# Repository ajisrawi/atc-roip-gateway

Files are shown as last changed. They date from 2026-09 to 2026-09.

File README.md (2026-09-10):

# ATC RoIP Gateway (VHF + HF, airborne)

Radio-over-IP gateway for aircraft ATC radios: bridges a VHF COM and an HF
transceiver to an IP network (Starlink aviation terminal) with an ED-137-style
RTP audio + PTT/COR stream.

```
Pilot/remote op ⇄ RTP over IP (Starlink) ⇄ [this gateway] ⇄ VHF COM + HF transceivers
```

## Deliverables

| Item | Where | Status |
|---|---|---|
| **Design document (PDF)** | `ATC-RoIP-Gateway-Design-Document.pdf` | 16 pages: study, diagrams, PCB, BOM, verification + schematic appendix |
| **Market study** | `docs/01-market-study.md` | sourced |
| **Design spec** | `docs/02-design-spec.md` | rev A |
| **Schematics** | `hardware/atc-roip-gateway/*.kicad_sch` | ERC 0 errors / 0 warnings, wired stubs + net labels |
| **PCB (4-layer, 125×95 mm)** | `hardware/atc-roip-gateway/atc-roip-gateway.kicad_pcb` | fully routed, 0 unconnected, 0 electrical DRC |
| **Fab outputs** | `hardware/atc-roip-gateway/fab/` | Gerber ZIP, drill, pick-and-place |
| **BOM** | `docs/BOM.csv` | 40 line items, 100 parts, MPNs assigned |
| **Firmware** | `firmware/` | ED-137-style stack (SIP + RTP/PTT/SQU + G.711), CMake, flash script |
| **Generators** | `tools/` | schematic/PCB/BOM/doc generation + checks (reproducible) |

## Hardware summary
| Block | Part |
|---|---|
| MCU | STM32H743VIT6 (Ethernet MAC + SAI, runs lwIP + RTP) |
| Ethernet | LAN8742A RMII PHY + magnetics-integrated RJ45 |
| Audio | TLV320AIC23B stereo codec — Left = VHF, Right = HF |
| Radio isolation | 600:600 Ω transformers (RX/TX ×2), PC817 optos (PTT + COR ×2) |
| Radio connector | DB25 (pinout in design spec §5.1) |
| Power | 28 V DC bus → LM2576HV-5.0 buck → AMS1117-3.3, split analog rail |

## Regenerating everything
```bash
python tools/design.py            # schematics
python tools/make_bom.py          # BOM from netlist
python tools/make_design_doc.py   # design document PDF
# PCB: tools/make_pcb.py (placement) + Freerouting + tools/power_fanout_final.py
```

## Status / caveats
- Rev A prototype: not TSO'd, no DO-160 qualification, no DO-178C artifacts.
- ED-137: hardware + firmware structured for the ED-137B Radio profile; exact
  extension bit-fields and SDP attributes must be verified against the
  licensed EUROCAE text + a conformance tool before claiming compliance.
- Transformer footprint (DIP-4) and DB25 gender are placeholders — confirm
  against the chosen audio transformer and aircraft harness.
- Firmware builds against STM32CubeH7 (user fetches; see `firmware/README.md`)
  and needs the four board-config files copied per `firmware/src/config/README.md`.

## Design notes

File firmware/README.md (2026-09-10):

# ATC RoIP Gateway — Firmware

ED-137-style Radio-over-IP firmware for the STM32H743 gateway board:
SIP session endpoint + RTP audio (G.711 µ-law @ 8 kHz) with the ED-137
Radio-profile RTP header extension carrying PTT and squelch (SQU), R2S-style
keepalives, TLV320AIC23B codec driver, and isolated PTT/COR radio signaling.
Two channels: **VHF = left**, **HF = right** audio channel.

```
firmware/
├── CMakeLists.txt            build (arm-none-eabi-gcc, CMake)
├── cmake/arm-none-eabi.cmake toolchain file
├── flash.ps1                 flash helper (STM32CubeProgrammer CLI)
├── src/
│   ├── main.c                init + superloop
│   ├── board.h               pin map (matches schematic rev A)
│   ├── app_config.h          network / codec / behaviour settings
│   ├── ed137/
│   │   ├── rtp_ed137.h/.c    RTP + ED-137 header ext (PTT type, SQU), R2S
│   │   ├── sip_mini.h/.c     minimal SIP UA (INVITE/ACK/BYE/OPTIONS + SDP)
│   │   └── g711.h/.c         µ-law encode/decode
│   ├── audio/
│   │   ├── aic23.h/.c        TLV320AIC23B register driver (I2C)
│   │   └── sai_stream.h/.c   SAI1 DMA double-buffer streaming
│   ├── net/
│   │   └── roip_chan.h/.c    per-radio channel: jitter buffer, PTT/COR logic
│   └── dsp/
│       └── voxagc.h/.c       HPF + AGC + VOX squelch (HF conditioning)
└── third_party/              (you fetch: STM32CubeH7 → HAL + lwIP + CMSIS)
```

## Dependencies (fetch once)

The application code is self-contained; it builds against ST's HAL, CMSIS and
lwIP from the official STM32CubeH7 package:

```bash
git clone --depth 1 https://github.com/STMicroelectronics/STM32CubeH7 third_party/STM32CubeH7
```

Toolchain: [Arm GNU Toolchain](https://developer.arm.com/downloads/-/arm-gnu-toolchain-downloads)
(`arm-none-eabi-gcc`) and CMake ≥ 3.20 — or open the tree in **STM32CubeIDE**
and add `src/` to a generated STM32H743VITx project (easiest route).

## Build

```bash
cmake -B build -DCMAKE_TOOLCHAIN_FILE=cmake/arm-none-eabi.cmake
cmake --build build
```

Produces `build/atc-roip-gw.elf` / `.bin` / `.hex`.

## Flash (two ways)

**1. SWD via ST-LINK on header J2** (3V3, SWDIO, SWCLK, GND, NRST):

```powershell
./flash.ps1            # uses STM32_Programmer_CLI, SWD
```

**2. USB-less DFU fallback: system bootloader over UART on J3**
(BOOT0 high at reset → STM32 bootloader; then):

```powershell
STM32_Programmer_CLI -c port=COMx br=115200 -w build/atc-roip-gw.bin 0x08000000 -v -rst
```

Install [STM32CubeProgrammer](https://www.st.com/en/development-tools/stm32cubeprog.html)
for `STM32_Programmer_CLI`.

## Configuration

Edit `src/app_config.h` (static IP / DHCP, peer address, SIP on/off, codec
G.711 vs pass-through, VOX thresholds), or use the UART console on J3
(115200 8N1) at runtime — type `help`.

## ED-137 compliance status

Implemented toward the **ED-137B Radio profile**: SIP INVITE/ACK/BYE/OPTIONS
with WG67-style SDP (`a=type:radio`), RTP/PCMU 8 kHz, RTP header extension
carrying PTT type + SQU + PTT-id, and periodic R2S-style keepalive while idle.
The exact bit numbering of the extension word and the WG67 SDP attribute set
MUST be verified against the licensed EUROCAE ED-137B/C text and a conformance
tool (e.g. GL MAPS ED-137) before claiming compliance — constants live in one
place (`rtp_ed137.h`) to make that adjustment trivial.

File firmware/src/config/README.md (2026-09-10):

# Board config files (copy-and-adapt from STM32CubeH7)

This directory holds the four project-config files that STM32CubeH7 provides
as templates. Copy them from the Cube tree after cloning it and adjust:

| File | Copy from | Adjust |
|---|---|---|
| `stm32h7xx_hal_conf.h` | `Drivers/STM32H7xx_HAL_Driver/Inc/stm32h7xx_hal_conf_template.h` | enable HAL_ETH/SAI/I2C/UART/DMA modules, HSE_VALUE 25 MHz |
| `lwipopts.h` | any H7 lwIP example (`Projects/NUCLEO-H743ZI/Applications/LwIP/...`) | `NO_SYS 1`, `LWIP_DHCP 1`, UDP enabled, no TCP needed |
| `ethernetif.c/.h` | same lwIP example | RMII pins per `src/board.h` (PA1/PA2/PA7, PC1/PC4/PC5, PB11/PB12/PB13), PHY address 0 (LAN8742) |
| `STM32H743VITx_FLASH.ld` | `Projects/.../STM32H743ZITX_FLASH.ld` | add a `.dma_buf` section in D2 SRAM (0x30000000) for the SAI/ETH DMA buffers |

The NUCLEO-H743ZI lwIP example is the closest starting point — same MCU
family, same LAN8742 PHY, same RMII wiring except the TX_EN/TXD0/TXD1 port
choices, which `src/board.h` documents.

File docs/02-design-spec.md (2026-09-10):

# ATC RoIP Gateway — Design Specification

Airborne Radio-over-IP gateway that bridges **two aircraft transceivers (VHF COM +
HF)** to an **IP network (Starlink aviation terminal / aircraft LAN)** using an
ED-137-style RTP audio + PTT/COR signaling stream.

```
                             ┌─────────────────────────────────────────────┐
 VHF COM ──audio/PTT/COR──►  │  [radio_if]      [audio]      [mcu]   [eth] │
 HF XCVR ──audio/PTT/COR──►  │  transformers → TLV320AIC23 → STM32H7 → PHY ├──RJ45──► Starlink router
                             │  + PC817 optos    stereo codec  RTP/Opus    │           │
 28V DC bus ───────────────► │  [power] 28V → 5V buck → 3.3V / 3.3VA       │           ▼
                             └─────────────────────────────────────────────┘   ATC IP network / remote op
```

## KiCad project
`hardware/atc-roip-gateway/` — KiCad 8+ format (opens in KiCad 8/9/10).

| Sheet | File | Content |
|---|---|---|
| Root | `atc-roip-gateway.kicad_sch` | block notes + sheet index |
| Power | `power.kicad_sch` | 28 V bus input, protection, 5 V buck, 3.3 V LDO, analog rail split |
| MCU | `mcu.kicad_sch` | STM32H743VIT6, crystal, SWD, UART, PTT/COR GPIO, status LEDs |
| Ethernet | `ethernet.kicad_sch` | LAN8742A RMII PHY, 25 MHz crystal, magnetics-integrated RJ45 |
| Audio | `audio.kicad_sch` | TLV320AIC23B stereo codec (L = VHF, R = HF), coupling networks |
| Radio IF | `radio_if.kicad_sch` | 600 Ω isolation transformers ×4, PC817 optos ×4, DB25 |

Validation: `kicad-cli sch erc` — **0 errors, 0 warnings**; netlist connectivity
machine-checked (`tools/check_netlist.py`, 14 signal-path assertions + rail sizes).

The schematics are machine-generated (`tools/design.py` + `tools/kicad_gen.py`):
every pin carries a global label or power symbol rather than drawn wires. To
modify, edit `tools/design.py` and re-run `python tools/design.py`.

## Key design decisions

### One stereo codec, two radios
The TLV320AIC23B is a stereo 16/20/24/32-bit codec. **Left channel = VHF, right
channel = HF** for both ADC (radio RX audio → IP) and DAC (IP → radio mic input).
One I2S/SAI port on the MCU serves both radios with perfect sample alignment.
Airband AM and HF SSB voice are 300–2500 Hz; 8 kHz Fs suffices, 16 kHz recommended
with Opus.

### Galvanic isolation on every radio line
- **Audio:** 600:600 Ω transformers (T1–T4) on RX and TX paths of both channels —
  kills ground loops between the gateway and radios/audio panel (footprints are
  DIP-4 placeholders; fit e.g. Triad SP-66/TY-141P class parts).
- **PTT:** PC817 opto (U6/U8); collector–emitter keys the radio's PTT line to its
  own ground return (≤ 50 mA, ≤ 35 V — fit a transistor buffer or relay for HF
  couplers that key more current, and a TVS across the key line for tuner kick-back).
- **COR/squelch sense:** PC817 (U7/U9) driven by the radio's squelch/busy output
  through 4.7 kΩ; lets firmware do true carrier-operated squelch signaling in the
  RTP stream (VOX in DSP is the fallback when a radio has no COR output).

### STM32H743 + LAN8742A
480 MHz Cortex-M7 with hardware Ethernet MAC and SAI. Enough headroom for lwIP +
RTP + two Opus encoder/decoder pairs (or G.711 μ-law for ED-137 compatibility).
PHY strapped `nINTSEL` low → REF_CLK-out mode: the PHY sources the 50 MHz RMII
clock into PA1. MDIO pulled up 1.5 kΩ; PHY reset on PE10 with RC.

### Power: 28 V aircraft bus
Fuse → series Schottky (reverse polarity) → SMCJ33A TVS → **LM2576HV-5.0**
(60 V max input survives bus transients) → 5 V → AMS1117 → 3.3 V digital.
Ferrite beads split **+3.3VA/GNDA** for the codec analog side.
*DO-160 §16/17 compliance needs an upstream surge/holdup stage (e.g. active
clamp + holdup capacitance for 200 ms power interruption) — out of scope of rev A.*

## MCU pin allocation

| Function | Pins |
|---|---|
| RMII to LAN8742A | PA1 REF_CLK, PA2 MDIO, PC1 MDC, PA7 CRS_DV, PC4/PC5 RXD0/1, PB11 TX_EN, PB12/PB13 TXD0/1, PE10 PHY reset |
| SAI1 to codec | PE2 MCLK, PE5 BCLK, PE4 FS (LRCIN+LRCOUT), PE6 → DIN, PE3 ← DOUT |
| I2C1 (codec ctrl, addr 0x1A) | PB6 SCL, PB7 SDA (4.7 kΩ pull-ups) |
| PTT out | PD8 VHF, PD9 HF (→ 330 Ω → opto LED) |
| COR in | PD10 VHF, PD11 HF (10 kΩ pull-ups, opto pulls low) |
| Console / debug | USART1 PA9/PA10 (J3), SWD PA13/PA14 (J2) |
| Status LEDs | PD12/PD13/PD14 |

## DB25 radio connector (J5)

| Signal | VHF | HF | Notes |
|---|---|---|---|
| RX audio (hi/lo) | 1 / 14 | 6 / 19 | from radio speaker/600 Ω line out |
| Mic audio (hi/lo) | 2 / 15 | 7 / 20 | to radio mic input, level set by R25/R30 + trim |
| PTT (key/return) | 3 / 16 | 8 / 21 | opto collector/emitter, isolated |
| COR/squelch (hi/lo) | 4 / 17 | 9 / 22 | radio busy/squelch output drives opto LED |
| Chassis/common | 13, 25, shell | | |

## Firmware plan (not in this repo yet)
1. **Transport:** RTP over UDP; 20 ms frames; Opus @ 16 kbit/s VBR per channel
   (or G.711 μ-law 64 kbit/s for ED-137B Radio profile compatibility).
   PTT/squelch signaling in RTP header extension per ED-137 (R2S/PTT bits), or a
   simple side-channel UDP keepalive protocol for point-to-point use.
2. **Session:** static peer config first; SIP (ED-137 signalling) later.
3. **Jitter buffer:** adaptive 40–120 ms — sized for Starlink jitter.
4. **HF channel extras:** AGC, noise reduction, 300–2700 Hz bandpass, squelch DSP;
   key-line interlock delay for antenna coupler tune cycles.
5. **VOX fallback** when no COR line is wired.
6. **Config:** USART console + DHCP; later a tiny HTTP config page.

## Regulatory / safety notes
- This rev A design is **experimental / prototype** hardware: no TSO authorization,
  no DO-160 qualification, no DO-178C/DO-254 artifacts. Suitable for bench work,
  UAS, and experimental-category aircraft where the installer accepts responsibility.
- Transmitting on ATC frequencies requires an appropriately licensed radio and
  operator; the gateway only keys an already-certified transceiver.
- ATC voice relayed over Starlink is **not** an approved substitute for required
  VHF/HF/SATVOICE equipage in controlled airspace.

## Next steps
1. Review schematic PDF; adjust radio-side levels for the specific transceivers
   (e.g. mic input sensitivity, whether HF PTT needs a relay).
2. PCB layout (4-layer: SIG / GND / PWR / SIG; keep RMII short, isolate the
   transformer/opto zone from digital).
3. Firmware bring-up on a NUCLEO-H743ZI + codec breakout before spinning boards.
4. Bench test against an ED-137 test tool (GL MAPS or open-source RTP tooling).

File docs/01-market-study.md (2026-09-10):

# Market Study — Radio-over-IP Gateways for Airborne ATC Radio (VHF & HF)

**Date:** September 2026
**Question:** Does a Radio-over-IP (RoIP) gateway currently exist for *airborne* ATC
radios (VHF and HF), suitable for the architecture:

```
Pilot headset → Aircraft audio/RoIP gateway → Starlink → ATC IP network → Controller
```

## Summary answer

| Segment | Exists today? | Notes |
|---|---|---|
| **Ground-side ATC RoIP (VHF/HF ground stations)** | **Yes — mature & standardized** | EUROCAE **ED-137** (now rev C) defines VoIP for ATM: Controller Working Position (CWP), Ground Radio Station (GRS), Radio Media Gateway (RMG). Deployed worldwide (SESAR, FAA VoICE, ICAO Doc 9896). Vendors: Rohde & Schwarz, Frequentis, Jotron, GL Communications (test), VOCAL (stacks). |
| **Airborne VHF RoIP — UAV/BVLOS market** | **Yes — niche products** | Gateways that put a VHF airband radio on the aircraft and stream audio + PTT over the UAS datalink (LOS RF, cellular, or satcom) so a remote pilot can talk to ATC: Orbit Communication Systems Airborne Radio Gateway, Mimer SoftRadio, SyTech RoIP gateways. Patents exist for exactly this (e.g. US 9,281,890 — aeronautical radio voice+signaling over satellite IP; US 12,327,479 — ATC voice relay for UAS). |
| **Airborne HF RoIP gateway** | **No commercial product found** | HF-over-IP exists only on the *ground* side (remote HF ground stations of oceanic networks are IP-linked to centers). No airborne HF RoIP gateway product was identified — this is a genuine gap. |
| **ATC voice over Starlink (certified, crewed aviation)** | **No** | Starlink aviation terminals (STC'd on many types) carry generic broadband and VoIP calls, but there is **no certified path for controller–pilot voice over Starlink**. Oceanic/remote voice today is SATVOICE over Inmarsat/Iridium (certified LRCS), used as HF *backup* — and even SATVOICE is not yet accepted as a full HF replacement in most airspace. |

**Conclusion:** the exact product you describe — a single airborne gateway that fronts
both a VHF COM and an HF transceiver and streams them over an aircraft IP/Starlink
link — does **not exist** as a certified commercial product. Its building blocks all
exist (ED-137 on the ground, UAV VHF relay gateways, Starlink aviation broadband), so
a purpose-built gateway is a design gap worth filling — first for experimental /
UAS / flight-test use, since the certification path for crewed IFR use is long.

## What exists in detail

### 1. Ground infrastructure: ED-137 is the standard
EUROCAE WG-67's **ED-137** ("Interoperability Standard for VoIP ATM Components")
defines SIP session setup and RTP audio with PTT/squelch signaling carried in RTP
header extensions. Revisions: ED-137 (2009), A (2010), B (2012), C (2017-2020s).
It is the worldwide direction for ATC voice (SESAR, FAA VoICE program, ICAO Doc
9896). Any airborne gateway should speak an ED-137B/C Radio-profile-compatible
stream so it can plug into ground VCS (Voice Communication Systems) with minimal
adaptation.

### 2. Airborne RoIP today: the UAV/BVLOS niche
- **Orbit Communication Systems** — "Airborne Radio Gateway": ground operators
  access airborne radios over the UAS LOS/BLOS datalink to talk to ATC.
- **Mimer SoftRadio** — drone pilot talks to ATC through a VHF radio mounted on
  the UAV, from anywhere with Internet.
- **SyTech, VOCAL** — general RoIP gateways/stacks used in remote-pilot setups.
- Typical published architecture: VHF transceiver on the aircraft → RoIP gateway →
  audio digitized/compressed (~9.6 kbps) → UDP/RTP → satellite/cellular → ground.

These are VHF-only, mostly for unmanned aircraft, and none is a TSO'd avionics
article for crewed aircraft.

### 3. Long-range voice today: SATVOICE, not RoIP
For oceanic/remote airspace, certified long-range voice is **SATVOICE** via
Inmarsat (Aero H/H+) or Iridium, plus **CPDLC/ADS-C** datalink (FANS 1/A). SATVOICE
is accepted as a Long Range Communication System and HF backup; regulators still
generally require HF where HF is mandated, and CPDLC is not accepted for emergency/
non-routine comms. Iridium safety services are expanding toward enabling HF
relief in MMELs. Starlink has no aviation *safety-services* offering.

### 4. Why the gap exists (and what it means for the design)
- **Latency/QoS:** ED-137 assumes engineered ground networks; Starlink adds ~25–60 ms
  plus jitter and occasional outages — usable for AOC and experimental relay, hard to
  certify for tactical ATC voice today.
- **Certification:** a crewed-aircraft installation needs TSO/ETSO articles, DO-160
  environmental, DO-178C/DO-254 for software/hardware if it becomes required equipment.
  As *supplemental* equipment on experimental / restricted category aircraft (or UAS),
  the bar is far lower.
- **HF specifics:** HF SSB audio (300–2700 Hz, high noise, AGC pumping, tuner key-line
  interlocks) needs DSP conditioning that no off-the-shelf airborne RoIP box provides.

## Use cases for the designed gateway
1. **UAS/optionally-piloted aircraft:** remote pilot on the ground keys the aircraft's
   VHF/HF radios over Starlink — today's strongest commercial demand.
2. **Flight test / special mission:** stream live ATC audio to an ops center;
   record/timestamp both channels.
3. **Backup crew audio path:** pilot headset on the IP side (softphone) reaching the
   aircraft radios if the audio panel path is degraded (experimental aircraft only).
4. **HF trials:** remote HF operation trials (ham/MARS-style remoting is common
   practice on the ground; airborne remoting is unexplored).

## Sources
- [Radio over IP (RoIP) suppliers overview — Unmanned Systems Technology](https://www.unmannedsystemstechnology.com/expo/radio-over-ip-roip/)
- [Mimer SoftRadio RoIP platform, drone pilot ↔ ATC via onboard VHF](https://www.unmannedsystemstechnology.com/2023/06/mimer-softradio-roip-platform-adds-new-vhf-radio-compatibility/)
- [Orbit Communication Systems — Airborne Radio Gateway for UAS (PDF)](https://orbit-cs-usa.com/wp-content/uploads/2021/08/Radio-Gateway-for-UAS-_New_Brand.pdf)
- [SyTech Corporation — radio gateways & remote pilot UAV comms](https://www.sytechcorp.com/radio-gateways)
- [VOCAL — RoIP gateway and ED-137 VoIP ATM software](https://vocal.com/voip/roip/ed-137-voip-air-traffic-management/)
- [GL Communications — ED-137/ED-138 test tools; standard history](https://www.gl.com/test-solutions-for-voip-air-traffic-management.html)
- [Rohde & Schwarz — "ATC on its way to Voice over IP"](https://www.rohde-schwarz.com/us/applications/atc-on-its-way-to-voice-over-ip-application-card_56279-3841.html)
- [US Patent 9,281,890 — aeronautical radio voice & signaling over satellite IP](https://image-ppubs.uspto.gov/dirsearch-public/print/downloadPdf/9281890)
- [US Patent 12,327,479 — ATC voice relay for UAS over an aviation network](https://image-ppubs.uspto.gov/dirsearch-public/print/downloadPdf/12327479)
- [OPSGROUP — "The Big SATVOICE Question" (SATVOICE vs HF status)](https://ops.group/blog/the-big-satvoice-question/)
- [AirSatOne — SATVOICE LRCS via Iridium and Inmarsat](https://www.airsatone.com/satvoice-lrcs)
- [FAA AIP ENR 7.2 — oceanic data link / voice procedures](https://www.faa.gov/air_traffic/publications/atpubs/aip_html/part2_enr_section_7.2.html)
- [Pilot Mall — Starlink for general aviation status](https://www.pilotmall.com/blogs/news/high-speed-skies-is-starlink-ready-for-the-general-aviation-cockpit)
- [Survey of IP-based air-to-ground datalink technologies (ScienceDirect)](https://www.sciencedirect.com/science/article/pii/S0969699724000449)

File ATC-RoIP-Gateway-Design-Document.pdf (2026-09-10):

DESIGN DOCUMENT · REV A

# ATC Radio-over-IP Gateway

## Airborne VHF + HF RoIP over Starlink / aircraft IP

Pilot headset > gateway > Starlink > ATC IP network > controller

STM32H743 · LAN8742A Ethernet · TLV320AIC23B stereo codec Transformer-isolated audio · opto PTT / COR · 28 V aircraft bus

Project | ATC RoIP Gateway (VHF + HF, airborne)
Revision | A — schematic release
Date | 10 September 2026
Prepared by | eng.ahmad@gmail.com · generated with KiCad 10
Design status | ERC clean · netlist verified · PCB routed, 0 DRC electrical
Classification | Prototype / experimental — no TSO, DO-160, DO-178C

Appendix A contains the full KiCad schematic set (6 sheets, A3).

ATC Radio-over-IP Gateway — Design Document | Rev A · 10 Sep 2026

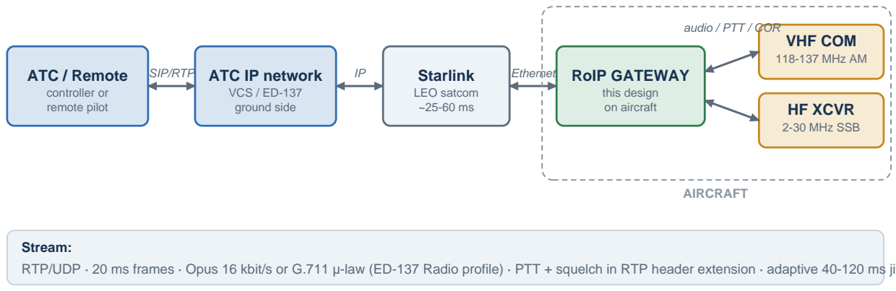
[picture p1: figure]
ATC / Remote controller or remote pilot; ATC IP network VCS / ED-137 ground side; Starlink LEO satcom ~25-60 ms; RoIP GATEWAY this design on aircraft; VHF COM 118-137 MHz AM; HF XCVR 2-30 MHz SSB; SIP/RTP; Ethernet; audio / PTT / COR; AIRCRAFT; Stream:

Prototype / experimental — not a certified avionics article | Page 2

# 1 Executive summary

This document specifies an airborne Radio-over-IP (RoIP) gateway that bridges two aircraft transceivers — a VHF COM and an HF radio — to an IP network carried by a Starlink aviation terminal. Voice is streamed as RTP with push-to-talk (PTT) and squelch/COR signaling in the style of EUROCAE ED-137, so a remote operator or ATC-side voice system can key and monitor the aircraft radios from anywhere on the network.
A market survey (Section 2) found no existing certified product with this scope: ground-side ATC VoIP is mature and standardized (ED-137), airborne VHF relays exist only in the UAV/BVLOS niche, and no airborne HF RoIP gateway was found at all. The hardware here fills that gap at prototype level: a single PCB built around an STM32H743 microcontroller, a LAN8742A Ethernet PHY, and a TLV320AIC23B stereo codec whose left and right channels carry the VHF and HF radios respectively, with full galvanic isolation toward both radios.
The complete schematic set was designed in KiCad (six hierarchical sheets, Appendix A), passes electrical rule check with zero errors and zero warnings, and its netlist has been machine-verified on fourteen critical signal paths.

# 2 Market context — what exists today

Segment | Status | Notes
Ground ATC RoIP | Mature, standardized | EUROCAE ED-137 (SIP + RTP with PTT/SQU header extensions); deployed under SESAR / FAA VoICE; vendors: R&S, Frequentis, Jotron.
Airborne VHF RoIP | Niche (UAV / BVLOS) | Orbit Airborne Radio Gateway, Mimer SoftRadio, SyTech: remote pilot talks to ATC through a VHF radio on the UAV via datalink / satcom.
Airborne HF RoIP | Not found | HF-over-IP exists only at ground stations of oceanic networks. A genuine product gap.
Voice over Starlink | Not certified | Starlink carries broadband / VoIP; certified long-range voice remains SATVOICE (Inmarsat / Iridium), itself still an HF backup, not a replacement.

Target applications, in order of practicality: (1) UAS / optionally piloted aircraft where the remote pilot keys the aircraft radios over Starlink; (2) flight test and special-mission audio streaming and recording; (3) experimental-aircraft backup audio paths; (4) airborne HF remote-operation trials.

# 3 System architecture

RTP/UDP · 20 ms frames · Opus 16 kbit/s or G.711 µ-law (ED-137 Radio profile) · PTT + squelch in RTP header extension · adaptive 40-120 ms jitter buffer

Figure 1 — End-to-end signal chain

The gateway sits on the aircraft LAN behind the Starlink router and terminates an RTP session per radio
channel. On the radio side it behaves like a remote operator position: it injects microphone audio and keys PTT, and it captures receiver audio together with the radio's carrier-operated squelch (COR) state. Latency budget over Starlink is typically 25–60 ms one-way plus jitter, which the adaptive jitter buffer absorbs; this is acceptable for remote-pilot and monitoring use but is one of the reasons tactical ATC certification is a long-term goal rather

Prototype / experimental — not a certified avionics article | Page 3

than a rev-A claim.

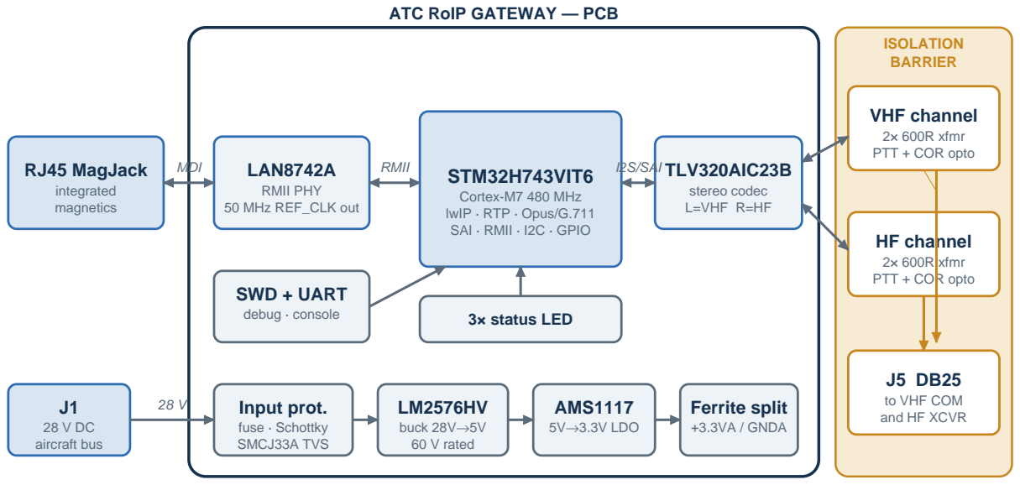
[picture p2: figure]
ATC RoIP GATEWAY — PCB; Input prot. fuse · Schottky SMCJ33A TVS; LM2576HV buck 28V→5V 60 V rated; AMS1117 5V→3.3V LDO; Ferrite split +3.3VA / GNDA; J1 28 V DC aircraft bus; STM32H743VIT6; Cortex-M7 480 MHz lwIP · RTP · Opus/G.711 SAI · RMII · I2C · GPIO; LAN8742A RMII PHY 50 MHz REF_CLK out; RJ45 MagJack integrated magnetics; MDI; RMII; TLV320AIC23B; stereo codec L=VHF R=HF; I2S/SAI; ISOLATION BARRIER; VHF channel 2× 600R xfmr PTT + COR opto; HF channel 2× 600R xfmr PTT + COR opto; J5 DB25 to VHF COM and HF XCVR; SWD + UART; debug · console; 3× status LED

Prototype / experimental — not a certified avionics article | Page 4

# 4 Hardware design

Figure 2 — Board block diagram (blocks map 1:1 to schematic sheets)

### 4.1 Processor and network

The STM32H743VIT6 (Cortex-M7, 480 MHz, LQFP-100) provides the Ethernet MAC, the SAI serial-audio interface, and enough compute headroom for lwIP plus two simultaneous Opus encoder/decoder pairs. The LAN8742A PHY connects over RMII; it is strapped (nINTSEL low) to source the 50 MHz RMII reference clock, saving a MCU clock output. The RJ45 jack has integrated magnetics; its center taps are biased from +3V3 through a ferrite bead per the PHY's drive scheme.

### 4.2 Audio path

A single TLV320AIC23B stereo codec serves both radios: left channel = VHF, right channel = HF, in both directions, giving perfectly aligned sampling from one SAI port. Airband AM and HF SSB voice occupy 300–2500 Hz, so 8 kHz sampling suffices (16 kHz recommended with Opus). The codec is controlled over I2C at address 0x1A and runs as I2S slave from SAI1 (MCLK, BCLK, FS).

### 4.3 Power

The 28 V DC aircraft bus enters through a fuse, a series Schottky for reverse polarity, and an SMCJ33A transient clamp. An LM2576HV-5.0 buck (60 V maximum input) survives bus transients and feeds an AMS1117-3.3 LDO. Ferrite beads split a dedicated +3.3VA / GNDA analog domain for the codec. Full DO-160 section 16/17 power quality (200 ms holdup, surge waveforms) requires an additional upstream stage and is deliberately out of scope for rev A.

### 4.4 Key components

Block | Part | Function
MCU | STM32H743VIT6 | lwIP + RTP + codec control, RMII MAC, SAI
Ethernet PHY | LAN8742A | RMII, REF_CLK-out strap, 1.5 kΩ MDIO pull-up
RJ45 | Amphenol RJMG1BD3B8K1ANR | Integrated magnetics + LEDs
Codec | TLV320AIC23BPW | Stereo ADC/DAC, I2S slave, I2C 0x1A

Prototype / experimental — not a certified avionics article | Page 5
Block | Part | Function
Audio isolation | 600:600 Ω transformers ×4 | RX + TX per channel (DIP-4 placeholder footprint)
PTT / COR | PC817 ×4 | Opto key-out and squelch sense per channel
Buck | LM2576HVS-5.0 | 28 V → 5 V, 3 A, 60 V rated
LDO | AMS1117-3.3 | 5 V → 3.3 V digital
Protection | SS54 + SMCJ33A | Reverse polarity + transient clamp

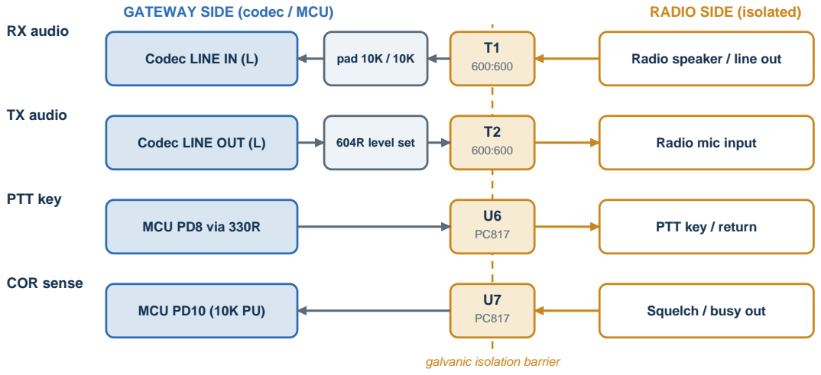
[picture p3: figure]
GATEWAY SIDE (codec / MCU); RADIO SIDE (isolated); galvanic isolation barrier; RX audio; Codec LINE IN (L); 600:600 pad 10K / 10K; Radio speaker / line out; TX audio; Codec LINE OUT (L); 600:600 604R level set; Radio mic input; PTT key; MCU PD8 via 330R; PTT key / return; COR sense; MCU PD10 (10K PU); Squelch / busy out

Prototype / experimental — not a certified avionics article | Page 6

# 5 Radio interface (isolation barrier)

Figure 3 — One radio channel (VHF shown; HF identical)

Every line to the radios crosses a galvanic isolation barrier, killing ground loops between the gateway, the airframe, and the radio installs. Receive and transmit audio each pass through a 600:600 Ω transformer; the receive side is padded 10 kΩ/10 kΩ before the codec line input and the transmit side has a 604 Ω series level-set resistor (trim per radio's mic sensitivity). PTT is keyed by a PC817 optocoupler whose collector–emitter closes the radio's PTT line to its own ground return (≤50 mA / 35 V — fit a relay or MOSFET buffer for HF couplers that key more current, and a TVS across the key line for antenna-tuner kick-back). The radio's squelch/busy output drives a second opto through 4.7 kΩ, giving the firmware a true COR input; DSP-based VOX is the fallback when a radio provides no COR line.

### 5.1 DB25 radio connector (J5)

Signal | VHF pins | HF pins | Notes
RX audio hi / lo | 1 / 14 | 6 / 19 | From radio speaker or 600 Ω line out
Mic audio hi / lo | 2 / 15 | 7 / 20 | To radio mic input, level set by series R
PTT key / return | 3 / 16 | 8 / 21 | Opto collector / emitter, isolated
COR hi / lo | 4 / 17 | 9 / 22 | Radio squelch/busy output drives opto LED
Chassis / common | 13, 25 | 13, 25 | Plus connector shell

### 5.2 MCU pin allocation

Function | Pins
RMII to LAN8742A | PA1 REF_CLK · PA2 MDIO · PC1 MDC · PA7 CRS_DV · PC4/PC5 RXD0/1 · PB11 TX_EN · PB12/PB13 TXD0/1 · PE10 PHY reset
SAI1 to codec | PE2 MCLK · PE5 BCLK · PE4 FS (LRCIN+LRCOUT) · PE6 → DIN · PE3 ← DOUT
I2C1 codec control | PB6 SCL · PB7 SDA (4.7 kΩ pull-ups)
PTT outputs | PD8 VHF · PD9 HF (330 Ω to opto LED)
COR inputs | PD10 VHF · PD11 HF (10 kΩ pull-ups, opto pulls low)
Debug / console | SWD PA13/PA14 (J2) · USART1 PA9/PA10 (J3)
Status LEDs | PD12 · PD13 · PD14

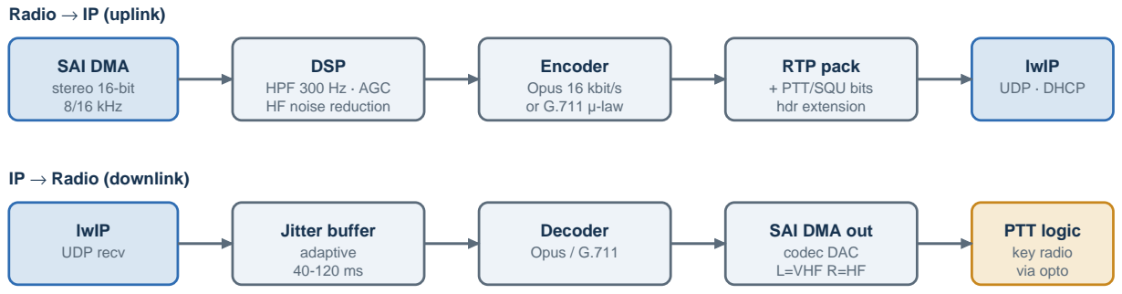
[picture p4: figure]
Radio → IP (uplink); SAI DMA stereo 16-bit 8/16 kHz; DSP HPF 300 Hz · AGC HF noise reduction; Encoder Opus 16 kbit/s or G.711 µ-law; RTP pack + PTT/SQU bits hdr extension; lwIP UDP · DHCP; IP → Radio (downlink); lwIP UDP recv; Jitter buffer adaptive 40-120 ms; Decoder Opus / G.711; SAI DMA out codec DAC L=VHF R=HF; PTT logic key radio via opto

Prototype / experimental — not a certified avionics article | Page 7

# 6 Firmware architecture

Figure 4 — Firmware dataflow (per radio channel)

- Transport: RTP over UDP, 20 ms frames; Opus 16 kbit/s VBR per channel, or G.711 µ-law 64 kbit/s for ED-137B Radio-profile compatibility. PTT and squelch travel in the RTP header extension (ED-137 R2S style).
- Session: statically configured peer for rev A; SIP session management (full ED-137 signaling) as a later increment.
- Jitter buffer: adaptive 40–120 ms, sized for Starlink jitter.
- HF channel extras: AGC, noise reduction, 300–2700 Hz bandpass, and a key-line interlock delay for antenna-coupler tune cycles.
- VOX fallback when no COR line is wired to a radio.
- Config: UART console + DHCP; small HTTP status page later.
This stack is implemented in the firmware/ tree: ED-137-style RTP with the PTT/SQU header extension and R2S keepalive (rtp_ed137.c), a minimal SIP endpoint answering INVITE/ACK/BYE/OPTIONS with WG67-flavoured SDP (sip_mini.c), G.711 u-law (g711.c), the TLV320AIC23B driver (aic23.c), SAI DMA streaming (sai_stream.c), per-channel jitter buffer and PTT/COR logic (roip_chan.c), and HPF/AGC/VOX conditioning (voxagc.c). It builds with CMake + arm-none-eabi-gcc against the official STM32CubeH7 HAL/lwIP and flashes over SWD (header J2) with STM32CubeProgrammer (flash.ps1) or via the ROM bootloader on the J3 UART.

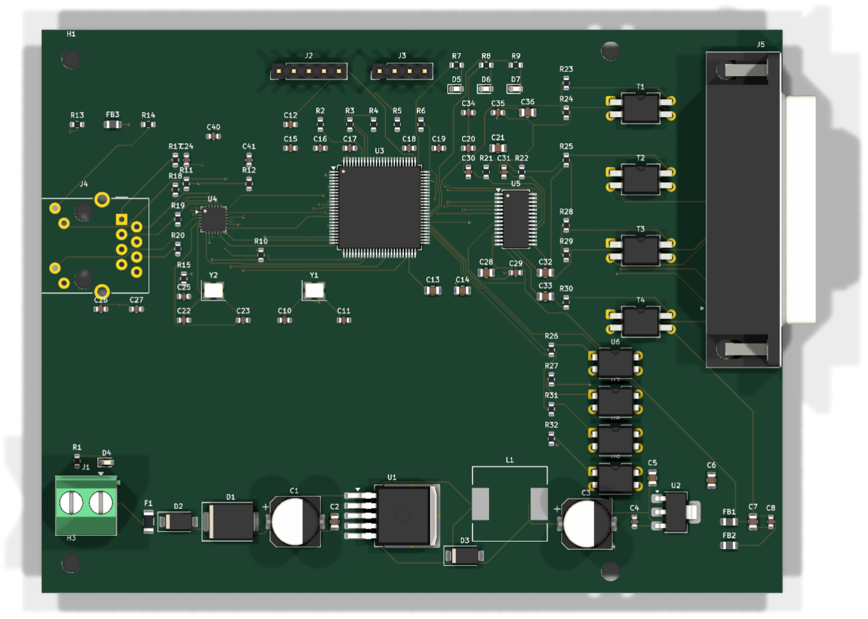
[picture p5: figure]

Prototype / experimental — not a certified avionics article | Page 8

# 7 PCB implementation

Figure 5 - Routed board, top side (125 x 95 mm, 4-layer)

The board is a 125 x 95 mm four-layer design: signals on the outer layers, solid GND (In1) and +3V3 (In2) planes inside. Floorplan: RJ45 with integrated magnetics and the LAN8742A PHY on the left edge, STM32H743 in the centre, TLV320AIC23B codec to its right, and the isolation zone - four 600 Ohm transformers, four PC817 optocouplers and the DB25 radio connector - along the right edge; the 28 V power chain runs along the bottom from the input terminal block through the buck and LDO. Routing: Freerouting autorouter constrained to the outer layers, then scripted collision-checked power fanout (86+ plane-stitching vias) and hand-verified repairs in congested areas. Rules: 0.2 mm min track, 0.15 mm clearance, 0.45/0.2 mm min via - standard 4-layer fab capability.
Manufacturing outputs (hardware/atc-roip-gateway/fab/): Gerbers, Excellon drill + map, pick-and-place CSV, and a ready-to-upload Gerber ZIP.

# 8 Bill of materials

Complete BOM: docs/BOM.csv - 40 line items, 100 components, with manufacturer part numbers. Summary:

References | Qty | Value | Manufacturer P/N
C1 | 1 | 100uF/63V | EEE-FK1J101P
C2 | 1 | 100nF/100V | CL21 series
C3 | 1 | 470uF/16V | EEE-FK1C471P
C4, C8, C12, C15, C16, C17,... | 16 | 100nF | CL10 series
C5, C6, C7, C28, C32, C33, C36 | 7 | 10uF | CL21 series
C10, C11, C22, C23 | 4 | 18pF | CL10 series
C13, C14 | 2 | 2.2uF | CL21 series
C21 | 1 | 4.7uF | CL21 series

Prototype / experimental — not a certified avionics article | Page 9
References | Qty | Value | Manufacturer P/N
C24, C30, C31 | 3 | 1uF | CL10 series
C27 | 1 | 10nF | CL10 series
D1 | 1 | SMCJ33A | SMCJ33A
D2, D3 | 2 | SS54 | SS54
D4 | 1 | PWR | 19-217/GHC-YR1S2/3T
D5 | 1 | STAT1 | 19-217/GHC-YR1S2/3T
D6 | 1 | STAT2 | 19-217/GHC-YR1S2/3T
D7 | 1 | STAT3 | 19-217/GHC-YR1S2/3T
F1 | 1 | 1A | 0451001.MRL
FB1, FB2, FB3 | 3 | 600R@100MHz | BLM21PG600SN1D
J1 | 1 | 28VDC_BUS_IN | 1715022 (MKDS 1,5/2-5,08)
J2 | 1 | SWD | PinHeader 1x05 2.54mm
J3 | 1 | CONSOLE_UART | PinHeader 1x04 2.54mm
J4 | 1 | RJ45_MagJack | RJMG1BD3B8K1ANR
J5 | 1 | TO_RADIOS | 182-025-113R531 (female) or L717SDB25P
L1 | 1 | 100uH/3A | SRP1265A-101M
R1, R7, R8, R9, R13, R14, R... | 8 | 330R | RC0603FR-07330RL
R2, R5, R6, R12, R15, R23, ... | 9 | 10K | RC0603FR-0710KL
R3, R4, R27, R32 | 4 | 4.7K | RC0603FR-074.7KL
R10 | 1 | 12.1K | RC0603FR-0712.1KL
R11 | 1 | 1.5K | RC0603FR-071.5KL
R17, R18, R19, R20 | 4 | 49.9R | RC0603FR-0749.9RL
R21, R22 | 2 | 47K | RC0603FR-0747KL
R25, R30 | 2 | 604R | RC0603FR-07604RL
T1, T2, T3, T4 | 4 | 600:600 | SP-66 (or Tamura TTC-108)
U1 | 1 | LM2576HVS-5.0 | LM2576HVS-5.0/NOPB
U2 | 1 | AMS1117-3.3 | AMS1117-3.3
U3 | 1 | STM32H743VIT6 | STM32H743VIT6
U4 | 1 | LAN8742A | LAN8742A-CZ-TR
U5 | 1 | TLV320AIC23BPW | TLV320AIC23BPWR
U6, U7, U8, U9 | 4 | PC817 | PC817X2NSZ9F
Y1, Y2 | 2 | 25MHz | ABM3-25.000MHZ-D2Y-T

Prototype / experimental — not a certified avionics article | Page 10

# 9 Verification

Schematic, netlist, PCB and fab outputs are machine-generated and machine-checked; every artifact is reproducible from tools/.

Check | Tool | Result
Electrical rule check (all sheets) | kicad-cli sch erc | 0 errors, 0 warnings
Netlist connectivity, 14 critical paths (RMII, SAI, I2C, PTT, COR, audio, power) | tools/check_netlist.py | 14 / 14 pass
Power rail membership | netlist audit | +3V3 41 pins, GND 62, GNDA 17, +3.3VA 7, +5V 6
PCB connectivity | kicad-cli pcb drc | 0 unconnected pads (fully routed)
PCB electrical rules (clearance, shorts, holes, edge) | kicad-cli pcb drc | 0 violations
PCB cosmetics | kicad-cli pcb drc | 13 silkscreen notes (connector artwork; fab-clipped)

# 10 Compliance and regulatory position

- ED-137: ED-137 is a protocol standard — compliance is earned in firmware and by conformance test. This hardware is ED-137-ready: G.711-capable 8 kHz codec, Ethernet, and real PTT/COR signal paths. Validation against an ED-137 test set (e.g. GL MAPS) is a firmware milestone.
- Certification: rev A is prototype/experimental hardware — no TSO authorization, no DO-160 qualification, no DO-178C/DO-254 artifacts. Suitable for bench, UAS, and experimental-category use.
- Spectrum: the gateway only keys an already-certified transceiver; transmissions on ATC frequencies require an appropriately licensed radio and operator.
- Operational: ATC voice over Starlink is not an approved substitute for required VHF/HF/SATVOICE equipage in controlled airspace.

# 11 Next steps

- Review radio-side levels against the specific transceivers (mic sensitivity, PTT current, HF coupler behaviour).
- Order boards from the fab ZIP; assemble, bring up power, then SWD.
- Firmware bring-up on NUCLEO-H743ZI + codec breakout before board spin.
- Bench test against an ED-137 radio emulator; then live-radio testing on the bench with dummy loads.

# Appendix A — Schematic sheets

The following six A3 sheets are the complete rev A schematic as plotted from KiCad: root/index, power supply, MCU, Ethernet, audio codec, and radio interface. Every pin carries a drawn wire stub with its net label; the netlist is the authoritative artifact and is what the Section 9 checks validate.

1 | 2 | 3 | 4 | 5 | 6 | 7 | 8
1 | 2 | 3 | 4 | 5 | 6 | 7 | 8

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
F Date:
KiCad E.D.A. 10.0.3
Size: A3 | Rev: A Id: 1/6

Title: ATC Radio-over-IP Gateway - VHF/HF airborne RoIP

File: atc-roip-gateway.kicad_sch

Sheet: /

ATC RoIP Gateway Project

Pilot/remote op <-> RTP/IP (Starlink) <-> this gateway <-> aircraft VHF+HF transceivers

MCU

File: mcu.kicad_sch

Ethernet File: ethernet.kicad_sch

Audio Codec

File: audio.kicad_sch | Radio Interface

File: radio_if.kicad_sch Power Supply File: power.kicad_sch

SIGNAL PATH: ATC controller/remote pilot (RTP over IP via Starlink) <-> RJ45 [ethernet] <-> STM32H743 [mcu] <->

TLV320AIC23B codec [audio] <-> isolation transformers + PTT/COR optos [radio_if] <-> VHF COM + HF transceivers via DB25

Power: 28VDC aircraft bus -> 5V buck -> 3.3V digital / 3.3VA analog [power]

NOTE: prototype / experimental hardware. Not a certified avionics article (no TSO/DO-160/DO-254 compliance claimed).

# VI 3 C5

# 2 GND

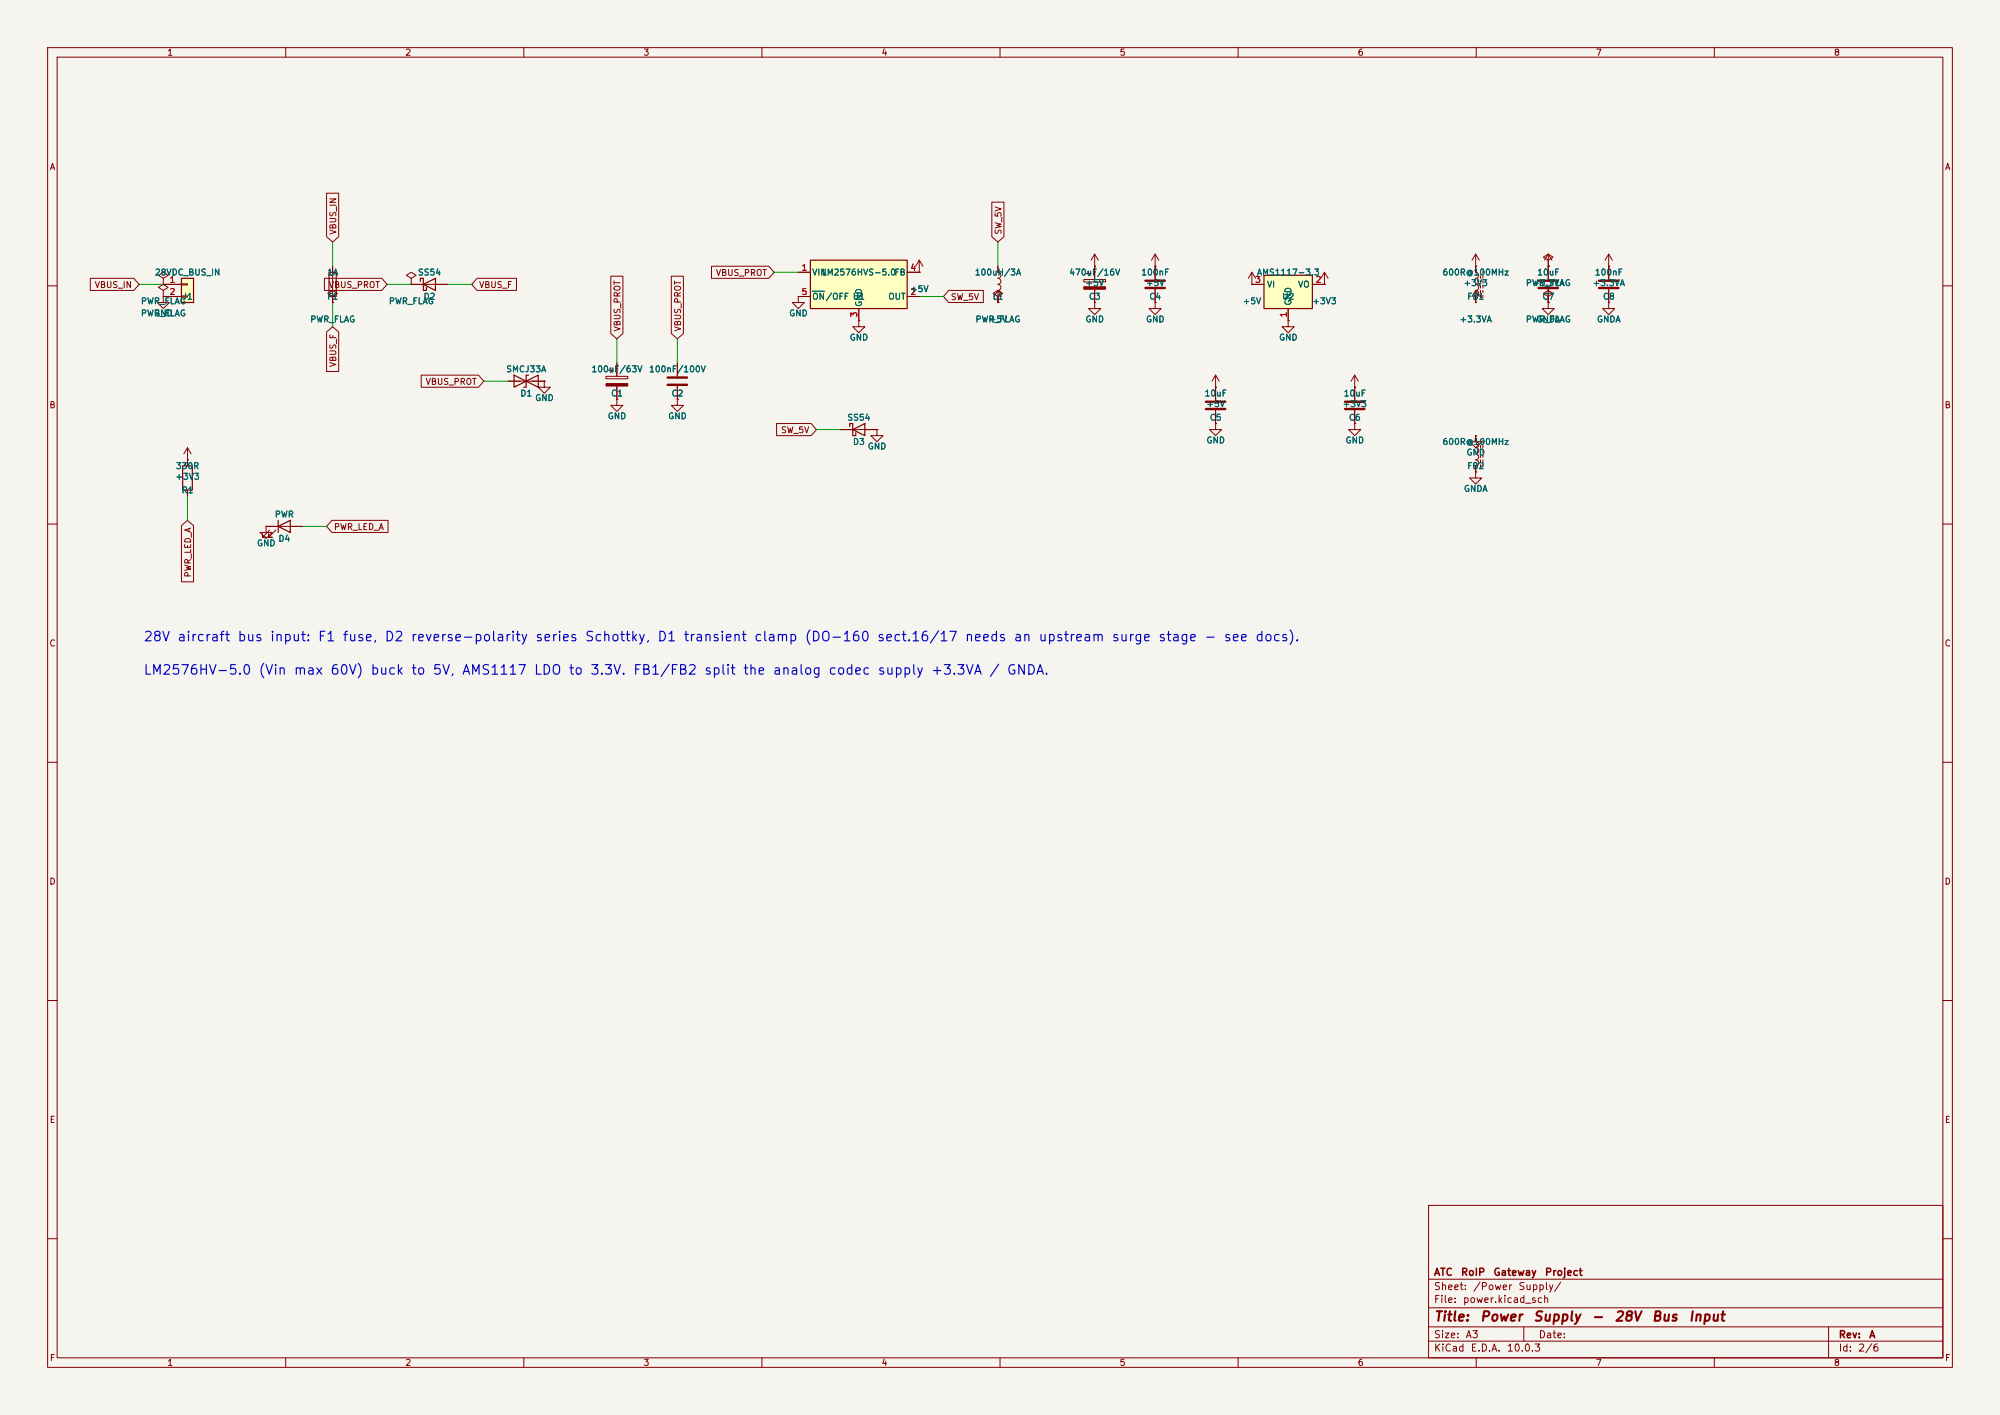
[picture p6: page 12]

PWR_FLAGJ1
28V aircraft bus input: F1 fuse, D2 reverse-polarity series Schottky, D1 transient clamp (DO-160 sect.16/17 needs an upstream surge stage - see docs). PWR_FLAG +5V

ATC RoIP Gateway Project
Sheet: /Power Supply/
File: power.kicad_sch
Title: Power Supply - 28V Bus Input

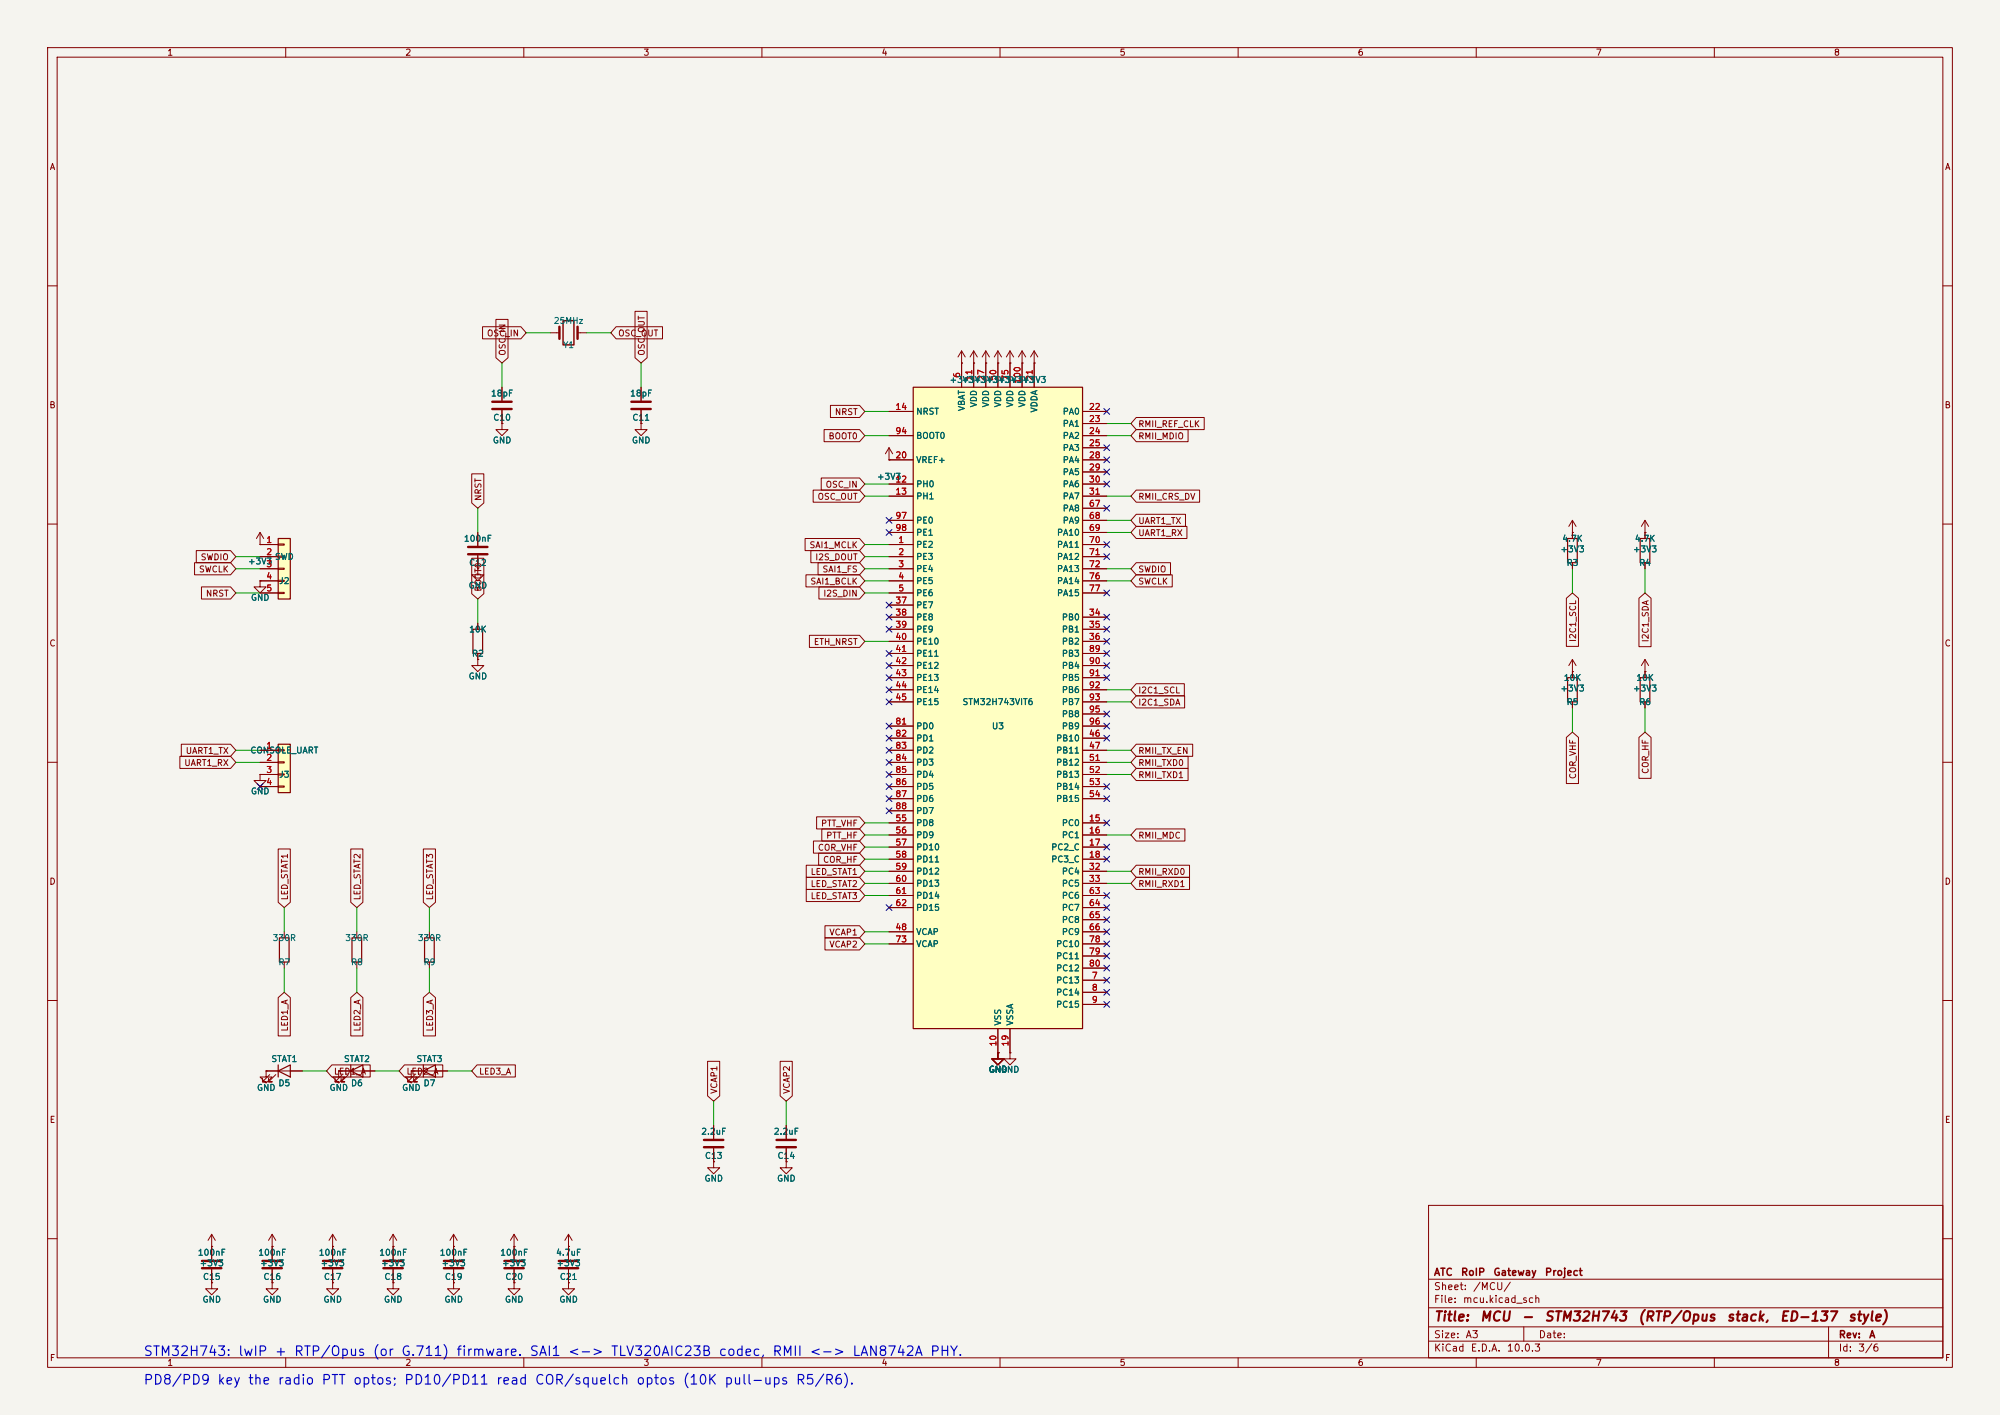
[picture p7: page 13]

ATC RoIP Gateway Project R8

Sheet: /MCU/
File: mcu.kicad_sch
Title: MCU - STM32H743 (RTP/Opus stack, ED-137 style)

STM32H743: lwIP + RTP/Opus (or G.711) firmware. SAI1 <-> TLV320AIC23B codec, RMII <-> LAN8742A PHY.
PD8/PD9 key the radio PTT optos; PD10/PD11 read COR/squelch optos (10K pull-ups R5/R6).

# 25MHz C25

# GND +3V3 C22

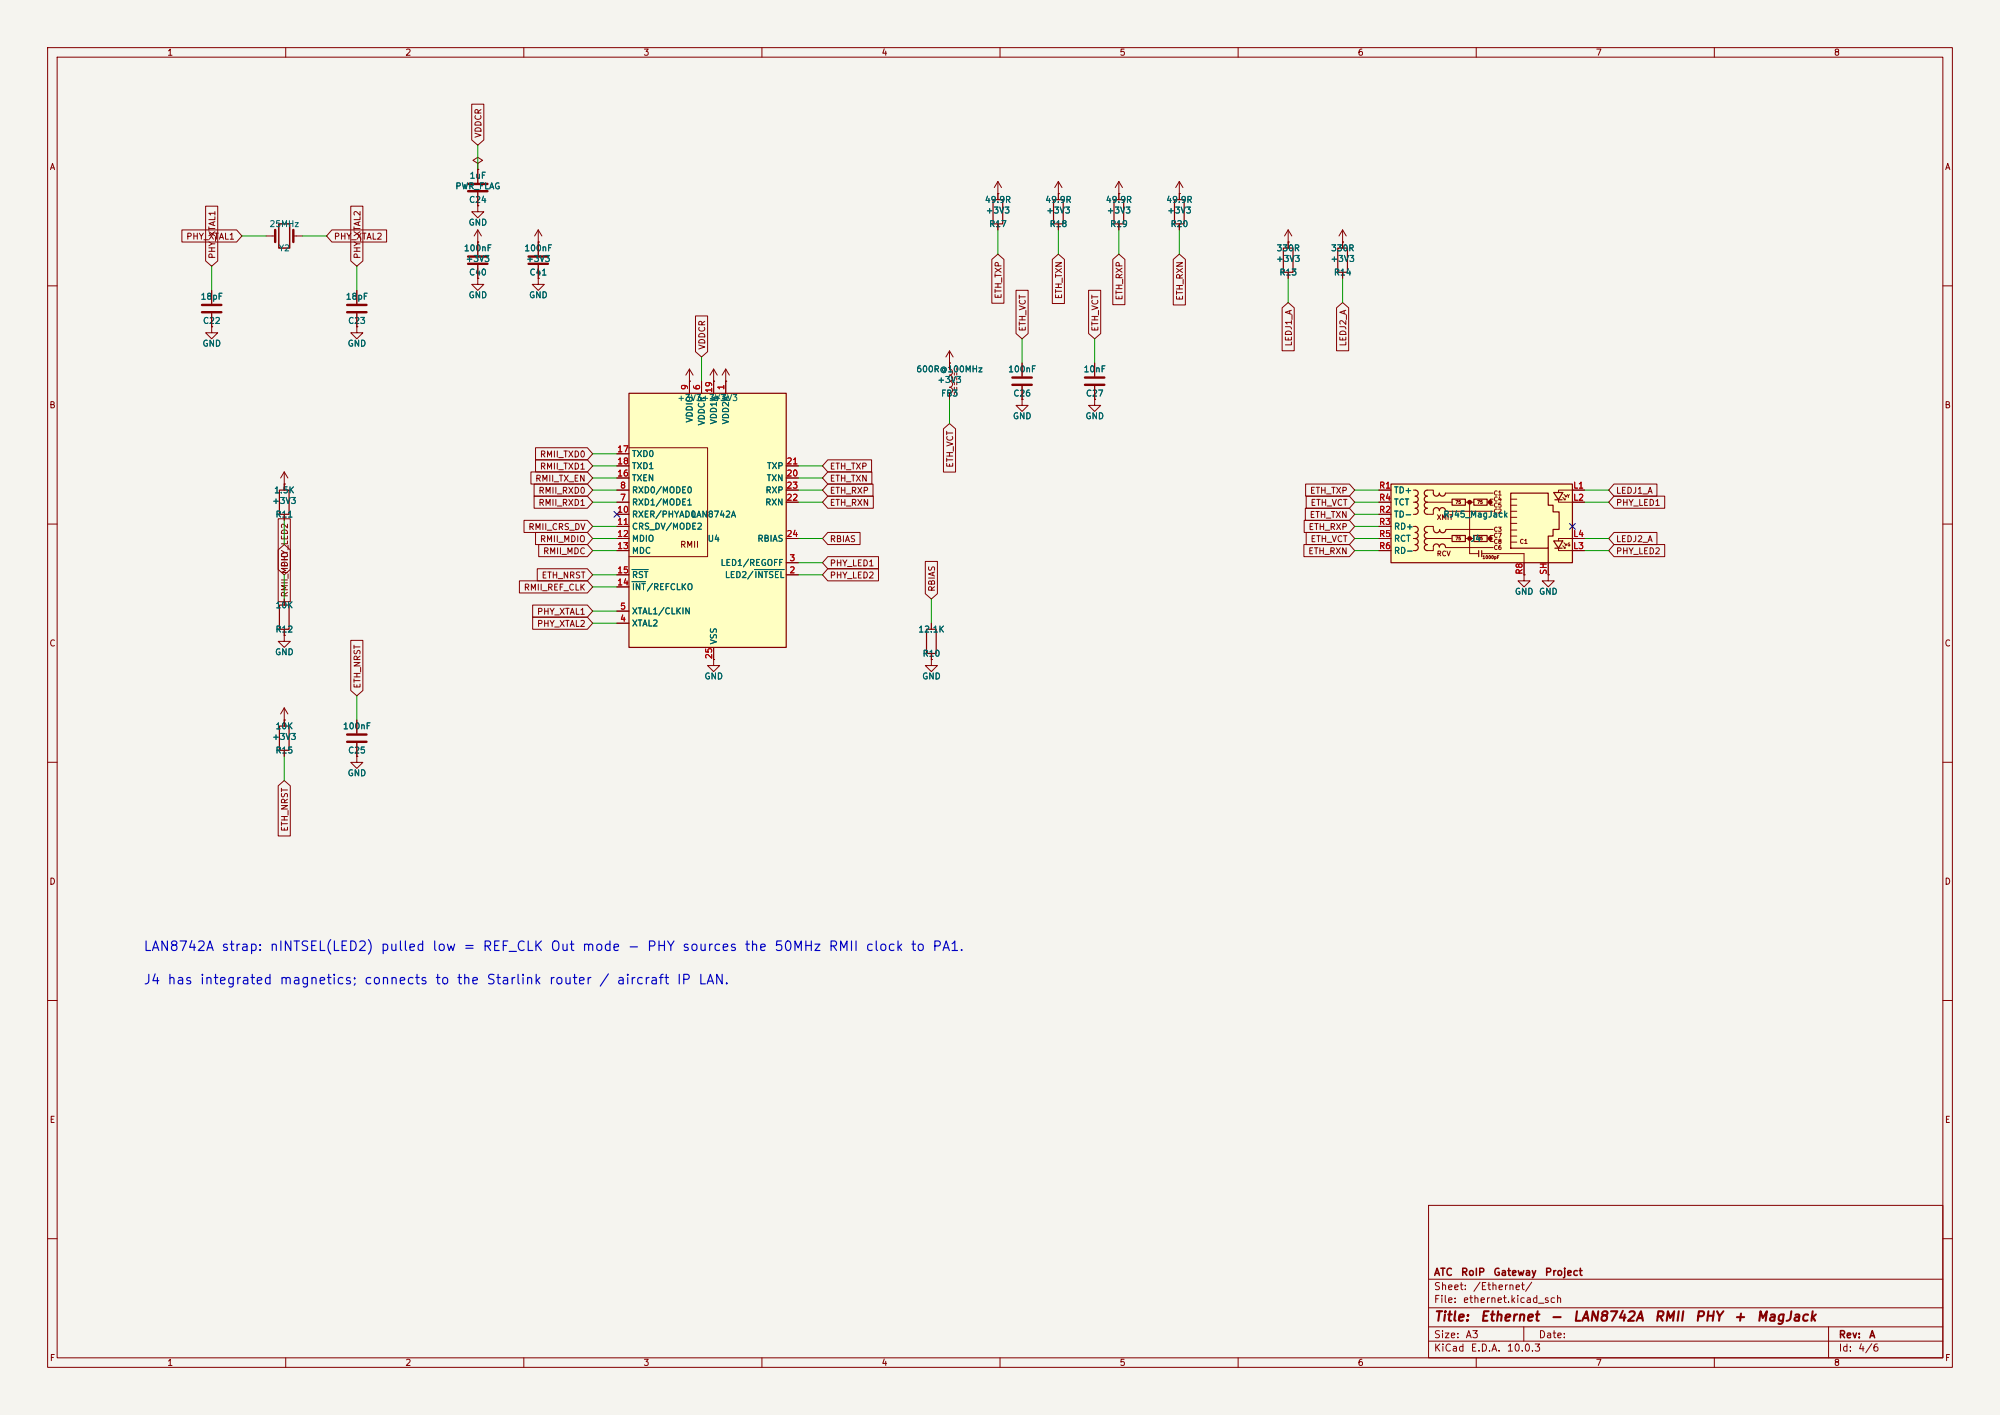
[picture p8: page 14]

TXN 20 TXP 21 RXN 22 RXP 23 RBIAS 24 VSS 25 U4

TXN 20 TXP 21 RXN 22 RXP 23 RBIAS 24 VSS 25

LAN8742A strap: nINTSEL(LED2) pulled low = REF_CLK Out mode - PHY sources the 50MHz RMII clock to PA1.

J4 has integrated magnetics; connects to the Starlink router / aircraft IP LAN.

ATC RoIP Gateway Project
Sheet: /Ethernet/
File: ethernet.kicad_sch
Title: Ethernet - LAN8742A RMII PHY + MagJack

# 100nF VHF_RX_C

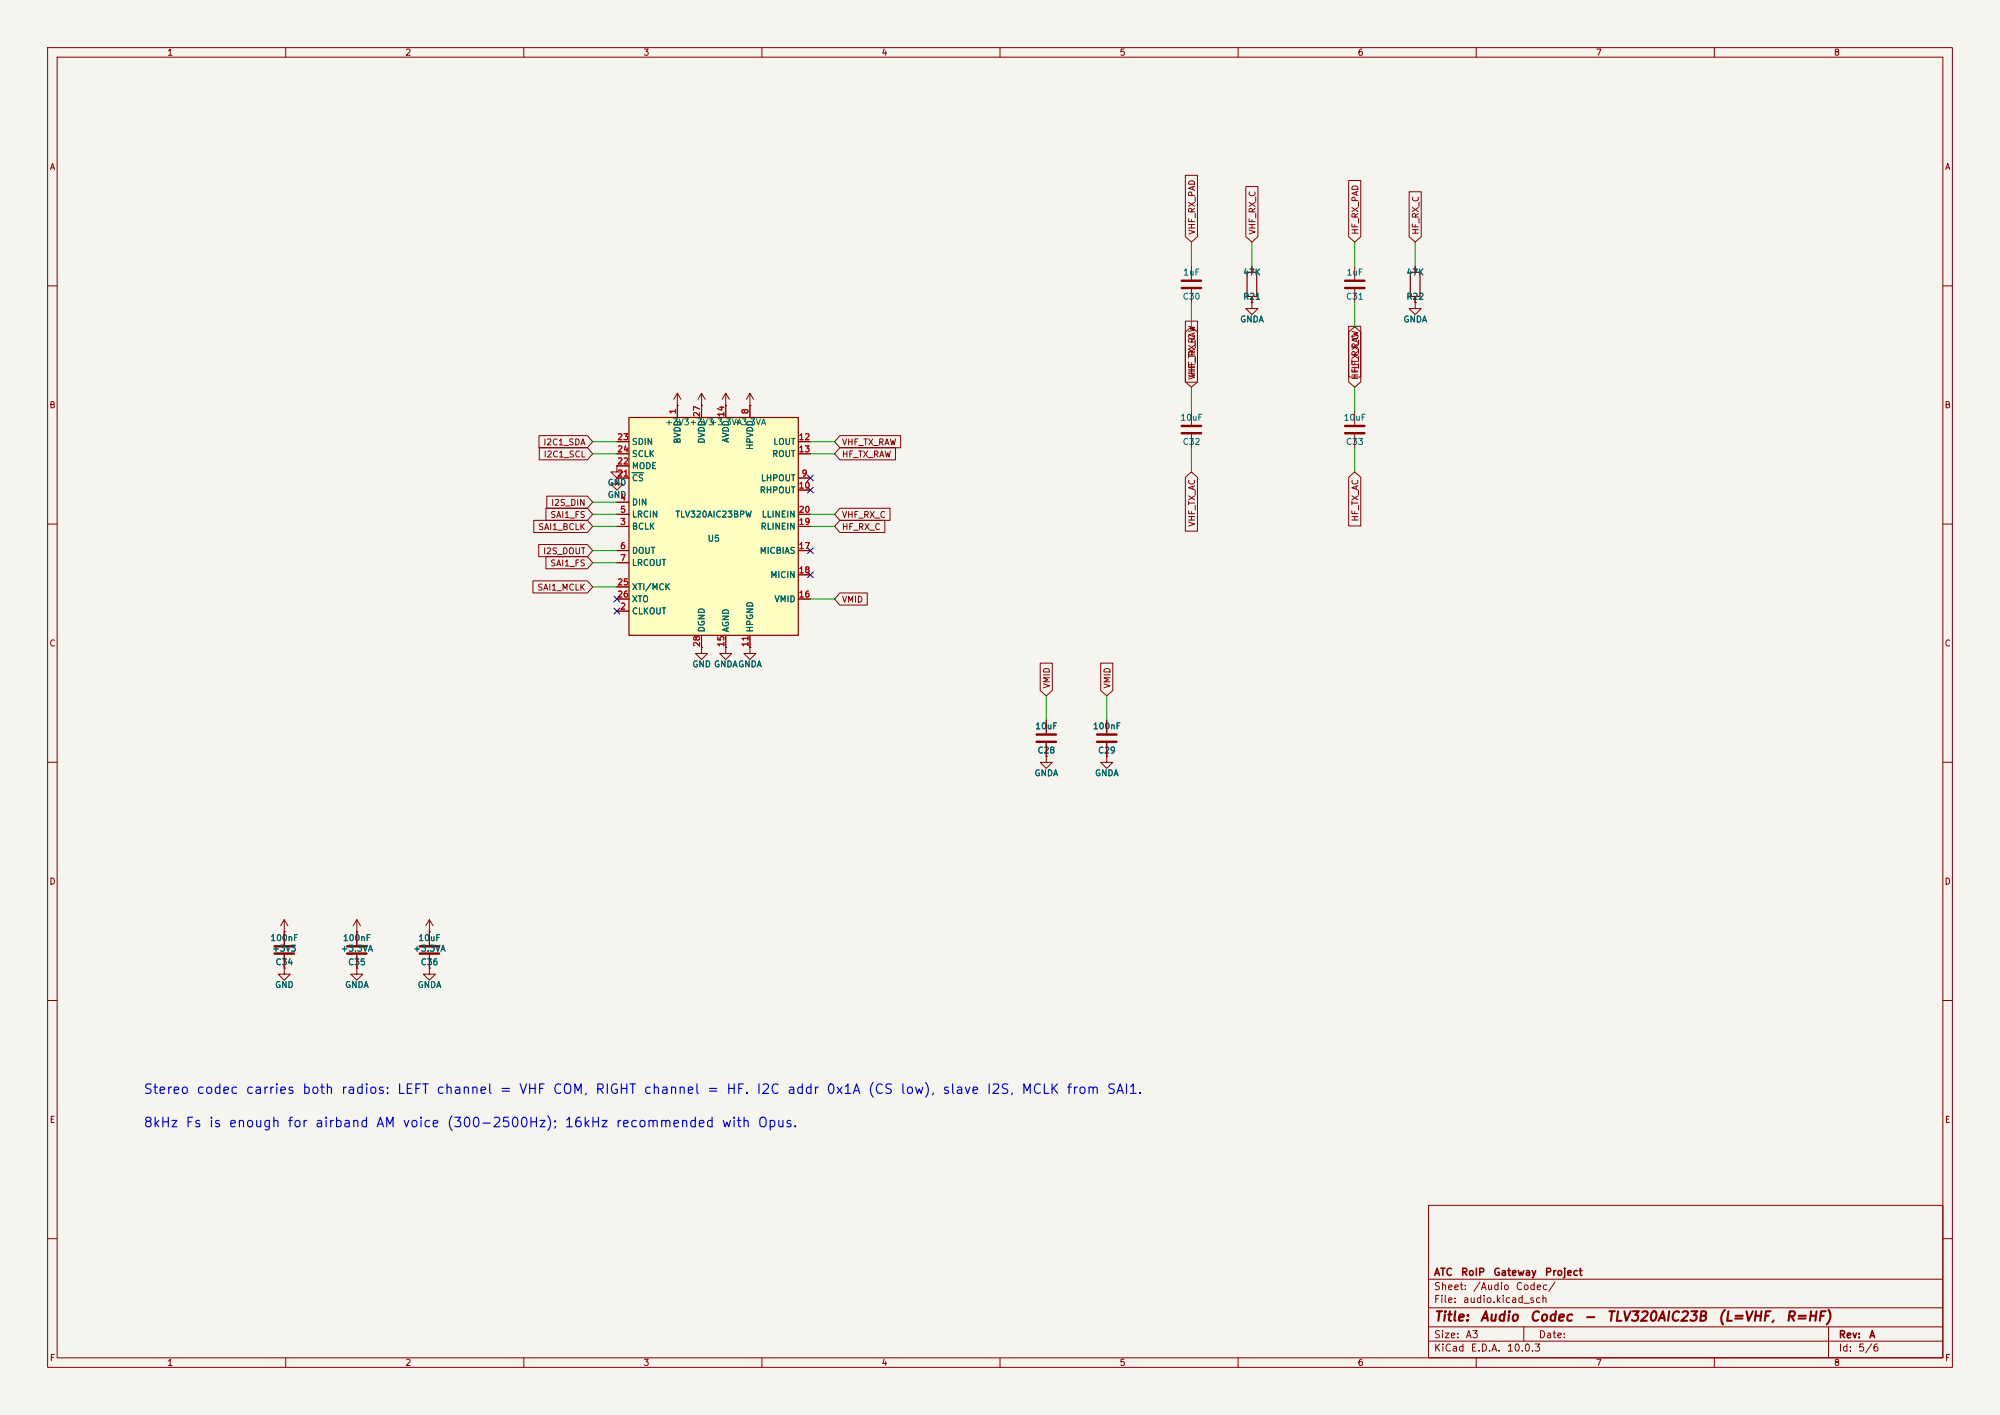
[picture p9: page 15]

SDIN 23
SCLK 24
VMID 16 MICBIAS 17 MICIN 18 RLINEIN 19 LLINEIN 20 CS 21 MODE 22
LHPOUT 9 RHPOUT 10 HPGND 11

GNDA GND
LOUT 12 ROUT 13 AVDD 14 AGND 15

1 CLKOUT 2 BCLK 3 DIN 4

VHF_RX_C Stereo codec carries both radios: LEFT channel = VHF COM, RIGHT channel = HF. I2C addr 0x1A (CS low), slave I2S, MCLK from SAI1.

8kHz Fs is enough for airband AM voice (300-2500Hz); 16kHz recommended with Opus.

ATC RoIP Gateway Project
Sheet: /Audio Codec/
File: audio.kicad_sch
Title: Audio Codec - TLV320AIC23B (L=VHF, R=HF)

# GNDA GND

# 600:600 GND

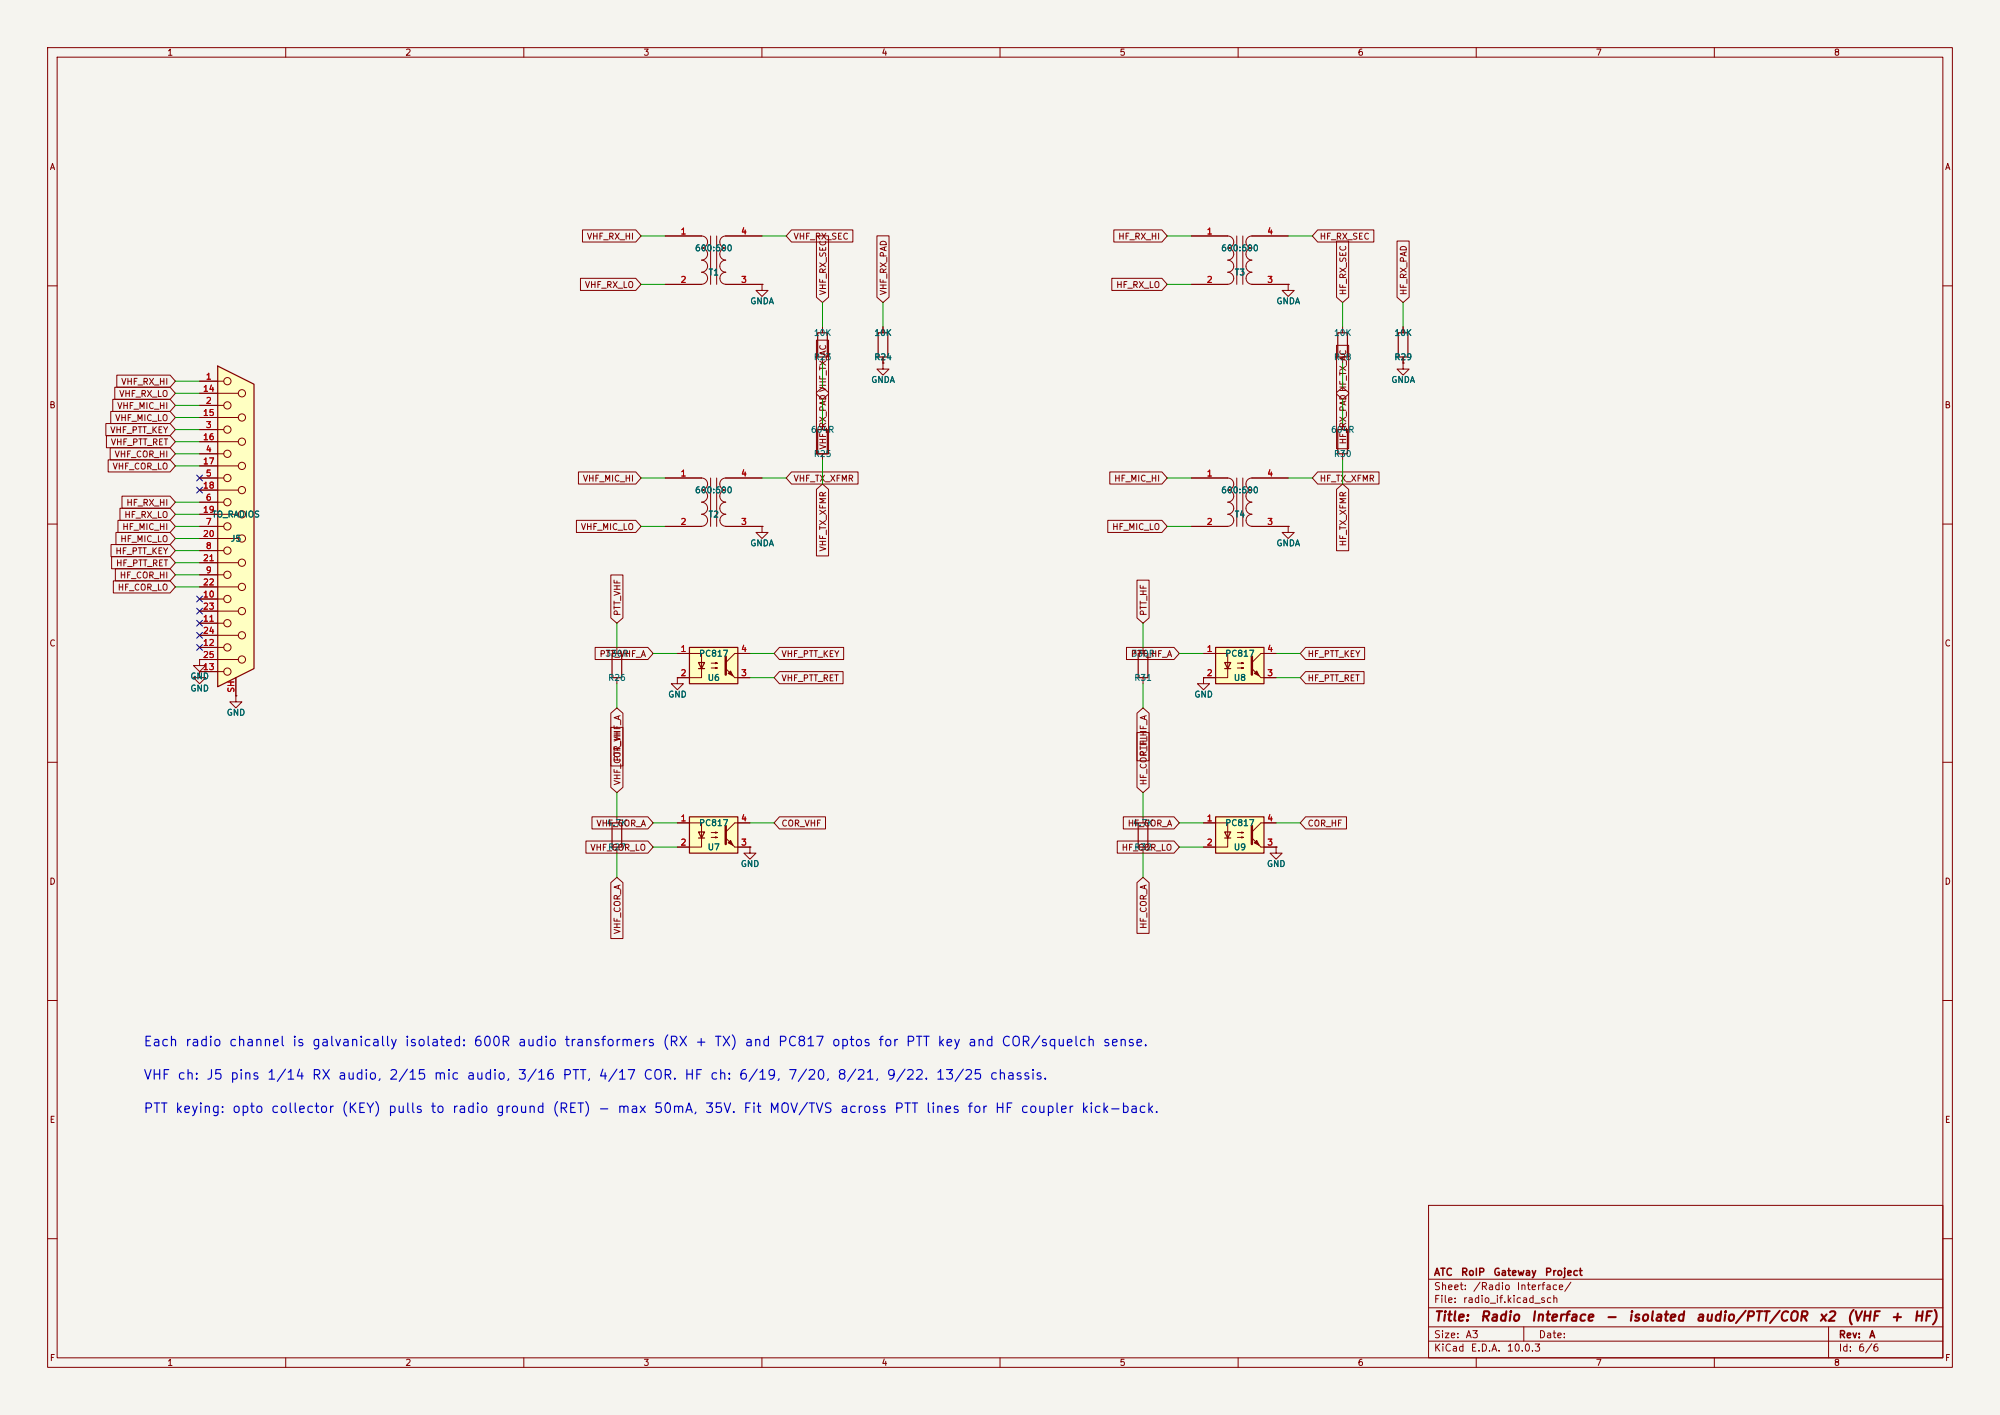
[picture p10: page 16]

Each radio channel is galvanically isolated: 600R audio transformers (RX + TX) and PC817 optos for PTT key and COR/squelch sense. GND

VHF ch: J5 pins 1/14 RX audio, 2/15 mic audio, 3/16 PTT, 4/17 COR. HF ch: 6/19, 7/20, 8/21, 9/22. 13/25 chassis.

PTT keying: opto collector (KEY) pulls to radio ground (RET) - max 50mA, 35V. Fit MOV/TVS across PTT lines for HF coupler kick-back.

ATC RoIP Gateway Project
Sheet: /Radio Interface/
File: radio_if.kicad_sch
Title: Radio Interface - isolated audio/PTT/COR x2 (VHF + HF)

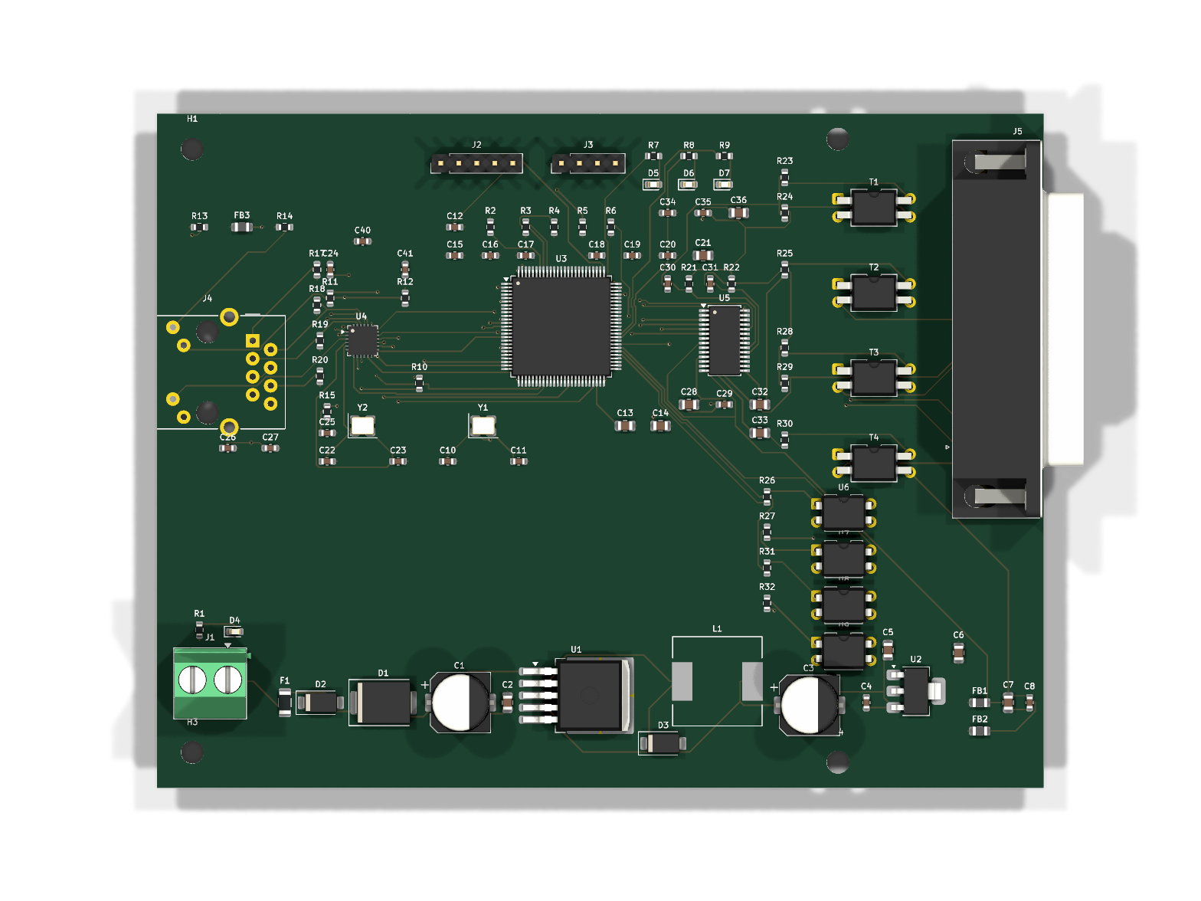
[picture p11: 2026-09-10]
hardware/atc-roip-gateway/board-top.png

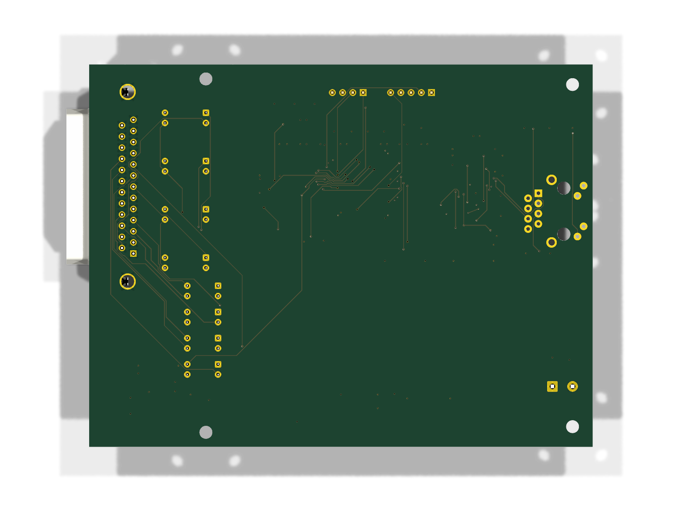
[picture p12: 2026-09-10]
hardware/atc-roip-gateway/board-bottom.png

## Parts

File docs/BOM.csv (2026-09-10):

References | Qty | Value | Description | Manufacturer | MPN | Footprint | Notes
C1 | 1 | 100uF/63V | Aluminum electrolytic 100uF 63V, SMD 8x10.2 | Panasonic | EEE-FK1J101P | CP_Elec_8x10
C2 | 1 | 100nF/100V | Capacitor 100nF/100V X7R/X5R 0805 | Samsung | CL21 series | C_0805_2012Metric
C3 | 1 | 470uF/16V | Aluminum electrolytic 470uF 16V, SMD 8x10.2 | Panasonic | EEE-FK1C471P | CP_Elec_8x10
C4, C8, C12, C15, C16, C17, C18, C19, C20, C25, C26, C29, C34, C35, C40, C41 | 16 | 100nF | Capacitor 100nF X7R 0603 (NP0 for 18pF) | Samsung | CL10 series | C_0603_1608Metric
C5, C6, C7, C28, C32, C33, C36 | 7 | 10uF | Capacitor 10uF X7R/X5R 0805 | Samsung | CL21 series | C_0805_2012Metric
C10, C11, C22, C23 | 4 | 18pF | Capacitor 18pF X7R 0603 (NP0 for 18pF) | Samsung | CL10 series | C_0603_1608Metric
C13, C14 | 2 | 2.2uF | Capacitor 2.2uF X7R/X5R 0805 | Samsung | CL21 series | C_0805_2012Metric
C21 | 1 | 4.7uF | Capacitor 4.7uF X7R/X5R 0805 | Samsung | CL21 series | C_0805_2012Metric
C24, C30, C31 | 3 | 1uF | Capacitor 1uF X7R 0603 (NP0 for 18pF) | Samsung | CL10 series | C_0603_1608Metric
C27 | 1 | 10nF | Capacitor 10nF X7R 0603 (NP0 for 18pF) | Samsung | CL10 series | C_0603_1608Metric
D1 | 1 | SMCJ33A | TVS diode 33V standoff, 1500W, SMC | Littelfuse | SMCJ33A | D_SMC
D2, D3 | 2 | SS54 | Schottky diode 40V 5A, SMA | Vishay / MDD | SS54 | D_SMA
D4 | 1 | PWR | LED green 0603 | Everlight | 19-217/GHC-YR1S2/3T | LED_0603_1608Metric
D5 | 1 | STAT1 | LED green 0603 | Everlight | 19-217/GHC-YR1S2/3T | LED_0603_1608Metric
D6 | 1 | STAT2 | LED green 0603 | Everlight | 19-217/GHC-YR1S2/3T | LED_0603_1608Metric
D7 | 1 | STAT3 | LED green 0603 | Everlight | 19-217/GHC-YR1S2/3T | LED_0603_1608Metric
F1 | 1 | 1A | Fuse 1A fast, 1206 | Littelfuse | 0451001.MRL | Fuse_1206_3216Metric
FB1, FB2, FB3 | 3 | 600R@100MHz | Ferrite bead 600R @ 100MHz, 0805 | Murata | BLM21PG600SN1D | L_0805_2012Metric
J1 | 1 | 28VDC_BUS_IN | 2-pos screw terminal block, 5.08mm | Phoenix Contact | 1715022 (MKDS 1,5/2-5,08) | TerminalBlock_Phoenix_MKDS-1,5-2_1x02_P5.00mm_Horizontal
J2 | 1 | SWD | SWD debug header | generic | PinHeader 1x05 2.54mm | PinHeader_1x05_P2.54mm_Vertical
J3 | 1 | CONSOLE_UART | Console UART header | generic | PinHeader 1x04 2.54mm | PinHeader_1x04_P2.54mm_Vertical
J4 | 1 | RJ45_MagJack | RJ45 jack with integrated 10/100 magnetics + LEDs | Amphenol | RJMG1BD3B8K1ANR | RJ45_Amphenol_RJMG1BD3B8K1ANR
J5 | 1 | TO_RADIOS | DB25 D-sub connector, horizontal PCB mount | NorComp / Amphenol | 182-025-113R531 (female) or L717SDB25P | DSUB-25_Pins_Horizontal_P2.77x2.84mm_EdgePinOffset7.70mm_Housed_MountingHolesOffset9.12mm | Choose male/female per aircraft harness; footprint is male-pins
L1 | 1 | 100uH/3A | Power inductor 100uH 3A shielded | Bourns | SRP1265A-101M | L_12x12mm_H8mm
R1, R7, R8, R9, R13, R14, R26, R31 | 8 | 330R | Resistor 330R 1% 0603 | Yageo | RC0603FR-07330RL | R_0603_1608Metric
R2, R5, R6, R12, R15, R23, R24, R28, R29 | 9 | 10K | Resistor 10K 1% 0603 | Yageo | RC0603FR-0710KL | R_0603_1608Metric
R3, R4, R27, R32 | 4 | 4.7K | Resistor 4.7K 1% 0603 | Yageo | RC0603FR-074.7KL | R_0603_1608Metric
R10 | 1 | 12.1K | Resistor 12.1K 1% 0603 | Yageo | RC0603FR-0712.1KL | R_0603_1608Metric
R11 | 1 | 1.5K | Resistor 1.5K 1% 0603 | Yageo | RC0603FR-071.5KL | R_0603_1608Metric
R17, R18, R19, R20 | 4 | 49.9R | Resistor 49.9R 1% 0603 | Yageo | RC0603FR-0749.9RL | R_0603_1608Metric
R21, R22 | 2 | 47K | Resistor 47K 1% 0603 | Yageo | RC0603FR-0747KL | R_0603_1608Metric
R25, R30 | 2 | 604R | Resistor 604R 1% 0603 | Yageo | RC0603FR-07604RL | R_0603_1608Metric
T1, T2, T3, T4 | 4 | 600:600 | Audio transformer 600:600 ohm, isolation | Triad Magnetics | SP-66 (or Tamura TTC-108) | DIP-4_W10.16mm | Footprint is DIP-4 placeholder - verify against chosen part
U1 | 1 | LM2576HVS-5.0 | Buck regulator 5V 3A, Vin max 60V, TO-263-5 | Texas Instruments | LM2576HVS-5.0/NOPB | TO-263-5_TabPin3
U2 | 1 | AMS1117-3.3 | LDO 3.3V 1A, SOT-223 | AMS / UMW | AMS1117-3.3 | SOT-223-3_TabPin2
U3 | 1 | STM32H743VIT6 | MCU Cortex-M7 480MHz, 2MB flash, ETH MAC, SAI, LQFP-100 | STMicroelectronics | STM32H743VIT6 | LQFP-100_14x14mm_P0.5mm
U4 | 1 | LAN8742A | 10/100 Ethernet PHY, RMII, QFN-24 | Microchip | LAN8742A-CZ-TR | QFN-24-1EP_4x4mm_P0.5mm_EP2.6x2.6mm
U5 | 1 | TLV320AIC23BPW | Stereo audio codec, I2S, TSSOP-28 | Texas Instruments | TLV320AIC23BPWR | TSSOP-28_4.4x9.7mm_P0.65mm
U6, U7, U8, U9 | 4 | PC817 | Optocoupler, transistor output, 5kV, DIP-4 | Sharp | PC817X2NSZ9F | DIP-4_W7.62mm
Y1, Y2 | 2 | 25MHz | Crystal 25MHz, 18pF CL, 3.2x2.5mm SMD | Abracon | ABM3-25.000MHZ-D2Y-T | Crystal_SMD_3225-4Pin_3.2x2.5mm

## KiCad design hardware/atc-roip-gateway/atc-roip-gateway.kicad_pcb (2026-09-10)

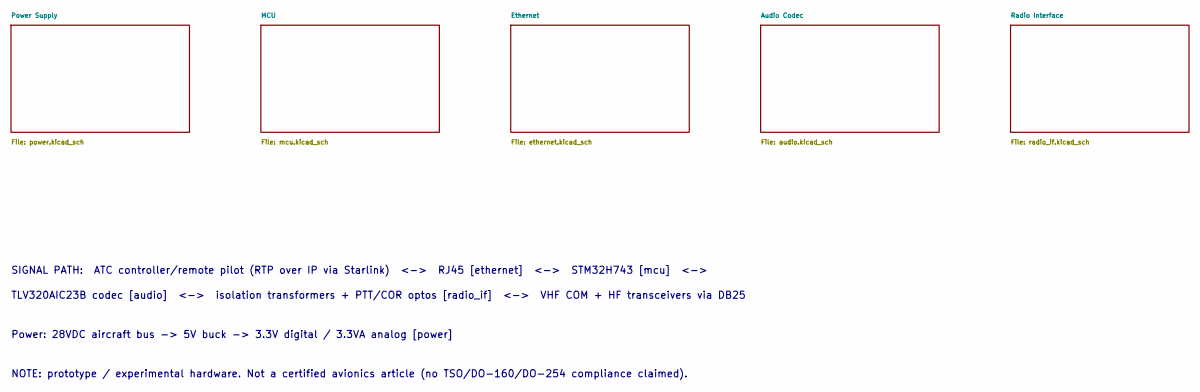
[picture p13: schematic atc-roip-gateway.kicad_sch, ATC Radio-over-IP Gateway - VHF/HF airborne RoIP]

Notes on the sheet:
SIGNAL PATH: ATC controller/remote pilot (RTP over IP via Starlink) <-> RJ45 [ethernet] <-> STM32H743 [mcu] <->
TLV320AIC23B codec [audio] <-> isolation transformers + PTT/COR optos [radio_if] <-> VHF COM + HF transceivers via DB25
Power: 28VDC aircraft bus -> 5V buck -> 3.3V digital / 3.3VA analog [power]
NOTE: prototype / experimental hardware. Not a certified avionics article (no TSO/DO-160/DO-254 compliance claimed).

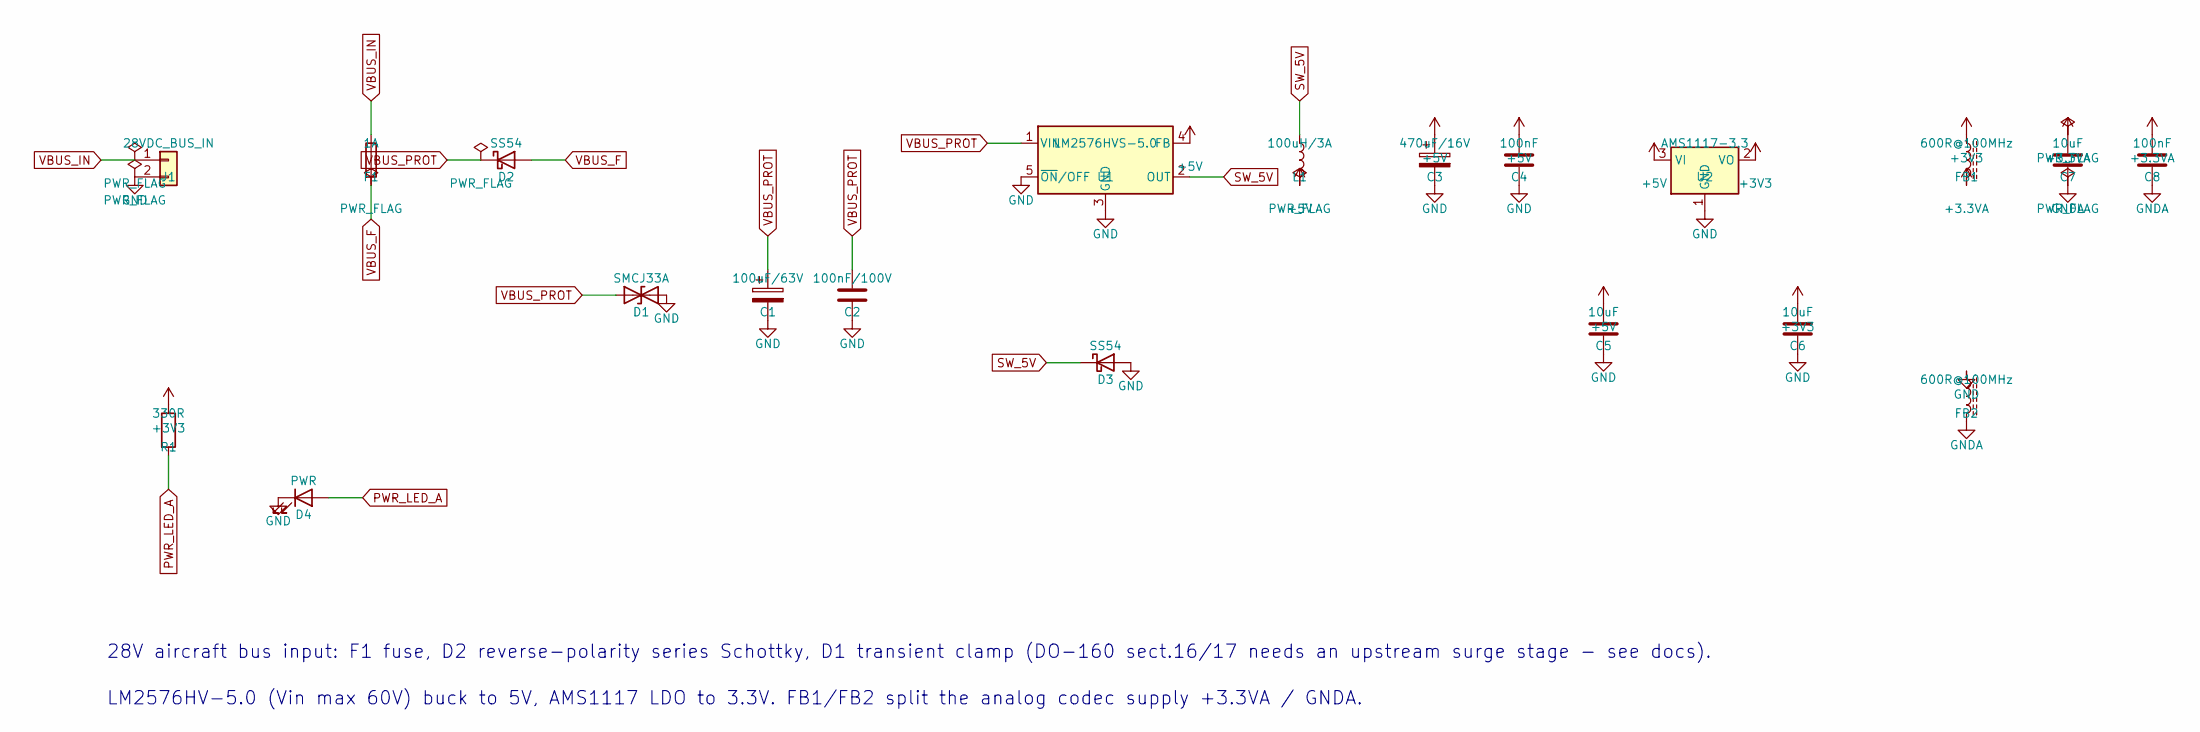
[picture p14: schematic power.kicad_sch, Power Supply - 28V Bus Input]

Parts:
C1: 100uF/63V; CP_Elec_8x10
C2: 100nF/100V; C_0805_2012Metric
C3: 470uF/16V; CP_Elec_8x10
C4, C8: 100nF; C_0603_1608Metric
C5, C6, C7: 10uF; C_0805_2012Metric
D1: SMCJ33A; D_SMC
D2, D3: SS54; D_SMA
D4: PWR; LED_0603_1608Metric
F1: 1A; Fuse_1206_3216Metric
FB1, FB2: 600R@100MHz; L_0805_2012Metric
J1: 28VDC_BUS_IN; TerminalBlock_Phoenix_MKDS-1,5-2_1x02_P5.00mm_Horizontal
L1: 100uH/3A; L_12x12mm_H8mm
R1: 330R; R_0603_1608Metric
U1: LM2576HVS-5.0; TO-263-5_TabPin3
U2: AMS1117-3.3; SOT-223-3_TabPin2

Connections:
+3V3: C6.1, FB1.1, R1.1, U2.2 (VO); also elsewhere on the board
PWR_LED_A: D4.2 (A), R1.2
SW_5V: D3.1 (K), L1.1, U1.2 (OUT)

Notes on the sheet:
28V aircraft bus input: F1 fuse, D2 reverse-polarity series Schottky, D1 transient clamp (DO-160 sect.16/17 needs an upstream surge stage - see docs).
LM2576HV-5.0 (Vin max 60V) buck to 5V, AMS1117 LDO to 3.3V. FB1/FB2 split the analog codec supply +3.3VA / GNDA.

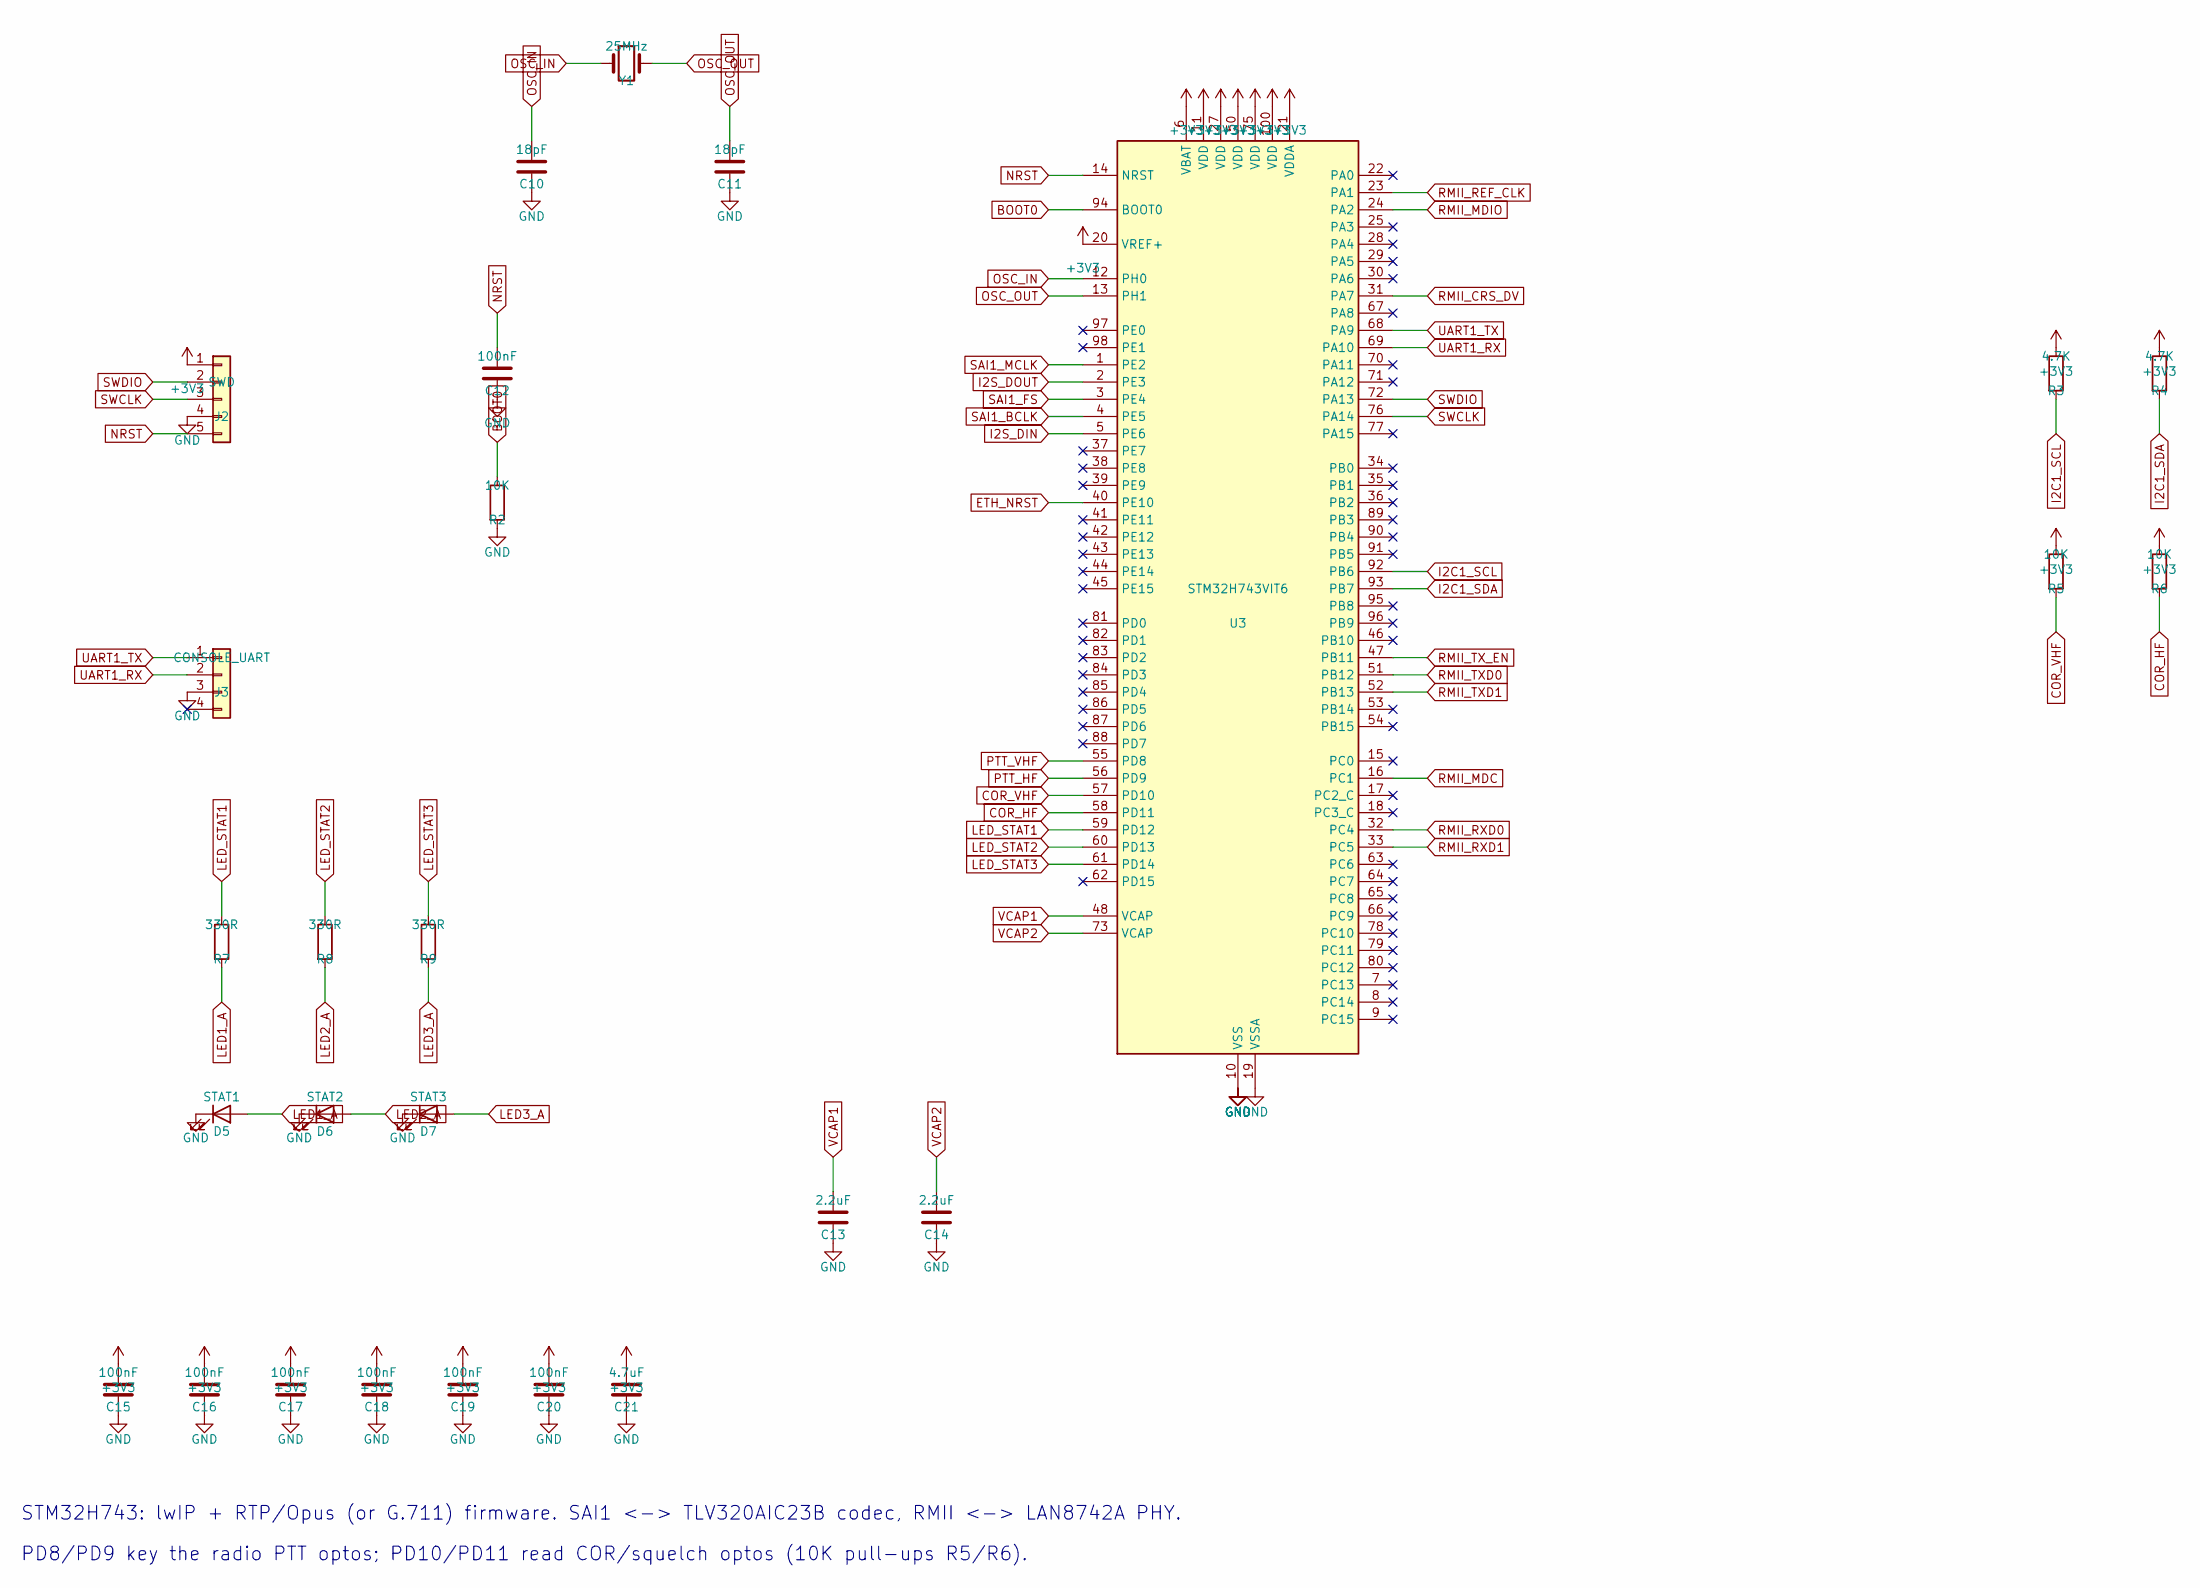
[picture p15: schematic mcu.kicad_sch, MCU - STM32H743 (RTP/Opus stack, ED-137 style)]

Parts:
C10, C11: 18pF; C_0603_1608Metric
C12, C15, C16, C17, C18, C19, C20: 100nF; C_0603_1608Metric
C13, C14: 2.2uF; C_0805_2012Metric
C21: 4.7uF; C_0805_2012Metric
D5: STAT1; LED_0603_1608Metric
D6: STAT2; LED_0603_1608Metric
D7: STAT3; LED_0603_1608Metric
J2: SWD; PinHeader_1x05_P2.54mm_Vertical
J3: CONSOLE_UART; PinHeader_1x04_P2.54mm_Vertical
R2, R5, R6: 10K; R_0603_1608Metric
R3, R4: 4.7K; R_0603_1608Metric
R7, R8, R9: 330R; R_0603_1608Metric
U3: STM32H743VIT6; LQFP-100_14x14mm_P0.5mm
Y1: 25MHz; Crystal_SMD_3225-4Pin_3.2x2.5mm

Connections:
+3V3: C15.1, C16.1, C17.1, C18.1, C19.1, C20.1, C21.1, J2.1, R3.1, R4.1, R5.1, R6.1, U3.6 (VBAT), U3.11 (VDD), U3.20 (VREF+), U3.21 (VDDA), U3.27 (VDD), U3.50 (VDD), U3.75 (VDD), U3.100 (VDD); also elsewhere on the board
BOOT0: R2.1, U3.94 (BOOT0)
COR_HF: R6.2, U3.58 (PD11); also elsewhere on the board
COR_VHF: R5.2, U3.57 (PD10); also elsewhere on the board
ETH_NRST: U3.40 (PE10); also elsewhere on the board
I2C1_SCL: R3.2, U3.92 (PB6); also elsewhere on the board
I2C1_SDA: R4.2, U3.93 (PB7); also elsewhere on the board
I2S_DIN: U3.5 (PE6); also elsewhere on the board
I2S_DOUT: U3.2 (PE3); also elsewhere on the board
LED1_A: D5.2 (A), R7.2
LED2_A: D6.2 (A), R8.2
LED3_A: D7.2 (A), R9.2
LED_STAT1: R7.1, U3.59 (PD12)
LED_STAT2: R8.1, U3.60 (PD13)
LED_STAT3: R9.1, U3.61 (PD14)
NRST: C12.1, J2.5, U3.14 (NRST)
OSC_IN: C10.1, U3.12 (PH0), Y1.1
OSC_OUT: C11.1, U3.13 (PH1), Y1.2
PTT_HF: U3.56 (PD9); also elsewhere on the board
PTT_VHF: U3.55 (PD8); also elsewhere on the board
RMII_CRS_DV: U3.31 (PA7); also elsewhere on the board
RMII_MDC: U3.16 (PC1); also elsewhere on the board
RMII_MDIO: U3.24 (PA2); also elsewhere on the board
RMII_REF_CLK: U3.23 (PA1); also elsewhere on the board
RMII_RXD0: U3.32 (PC4); also elsewhere on the board
RMII_RXD1: U3.33 (PC5); also elsewhere on the board
RMII_TXD0: U3.51 (PB12); also elsewhere on the board
RMII_TXD1: U3.52 (PB13); also elsewhere on the board
RMII_TX_EN: U3.47 (PB11); also elsewhere on the board
SAI1_BCLK: U3.4 (PE5); also elsewhere on the board
SAI1_FS: U3.3 (PE4); also elsewhere on the board
SAI1_MCLK: U3.1 (PE2); also elsewhere on the board
SWCLK: J2.3, U3.76 (PA14)
SWDIO: J2.2, U3.72 (PA13)
UART1_RX: J3.2, U3.69 (PA10)
UART1_TX: J3.1, U3.68 (PA9)
VCAP1: C13.1, U3.48 (VCAP)
VCAP2: C14.1, U3.73 (VCAP)

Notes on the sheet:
STM32H743: lwIP + RTP/Opus (or G.711) firmware. SAI1 <-> TLV320AIC23B codec, RMII <-> LAN8742A PHY.
PD8/PD9 key the radio PTT optos; PD10/PD11 read COR/squelch optos (10K pull-ups R5/R6).

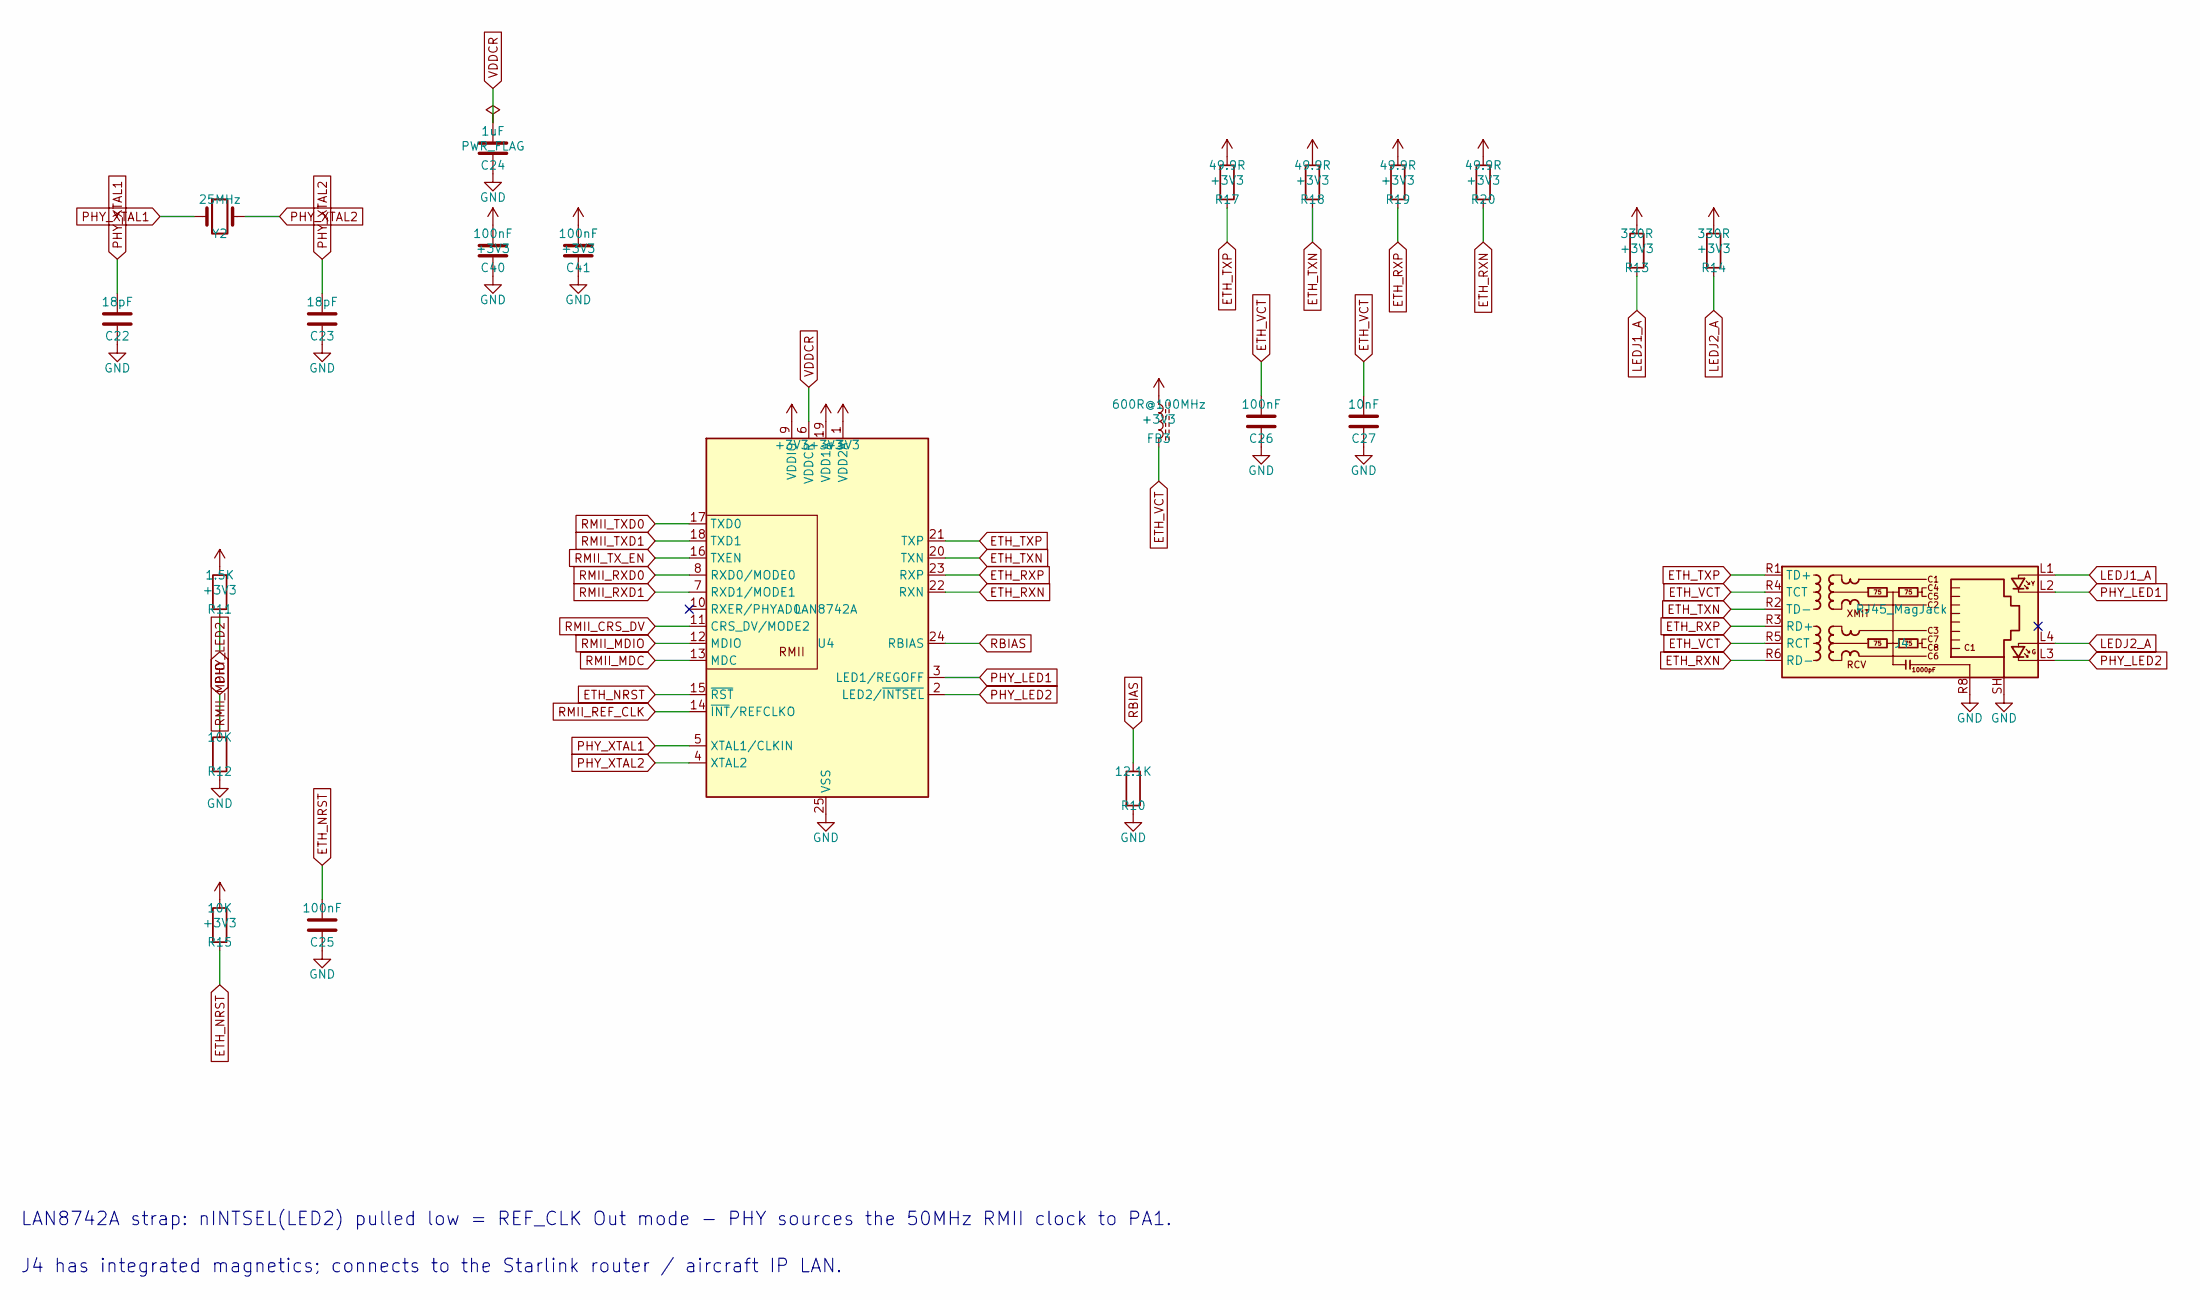
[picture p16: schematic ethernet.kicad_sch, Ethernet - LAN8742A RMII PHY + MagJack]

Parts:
C22, C23: 18pF; C_0603_1608Metric
C24: 1uF; C_0603_1608Metric
C25, C26, C40, C41: 100nF; C_0603_1608Metric
C27: 10nF; C_0603_1608Metric
FB3: 600R@100MHz; L_0805_2012Metric
J4: RJ45_MagJack; RJ45_Amphenol_RJMG1BD3B8K1ANR
R10: 12.1K; R_0603_1608Metric
R11: 1.5K; R_0603_1608Metric
R12, R15: 10K; R_0603_1608Metric
R13, R14: 330R; R_0603_1608Metric
R17, R18, R19, R20: 49.9R; R_0603_1608Metric
U4: LAN8742A; QFN-24-1EP_4x4mm_P0.5mm_EP2.6x2.6mm
Y2: 25MHz; Crystal_SMD_3225-4Pin_3.2x2.5mm

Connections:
+3V3: C40.1, C41.1, FB3.1, R11.1, R13.1, R14.1, R15.1, R17.1, R18.1, R19.1, R20.1, U4.1 (VDD2A), U4.9 (VDDIO), U4.19 (VDD1A); also elsewhere on the board
ETH_NRST: C25.1, R15.2, U4.15 (~RST); also elsewhere on the board
ETH_RXN: J4.R6 (RD-), R20.2, U4.22 (RXN)
ETH_RXP: J4.R3 (RD+), R19.2, U4.23 (RXP)
ETH_TXN: J4.R2 (TD-), R18.2, U4.20 (TXN)
ETH_TXP: J4.R1 (TD+), R17.2, U4.21 (TXP)
ETH_VCT: C26.1, C27.1, FB3.2, J4.R4 (TCT), J4.R5 (RCT)
LEDJ1_A: J4.L1, R13.2
LEDJ2_A: J4.L4, R14.2
PHY_LED1: J4.L2, U4.3 (LED1/REGOFF)
PHY_LED2: J4.L3, R12.1, U4.2 (LED2/~INTSEL)
PHY_XTAL1: C22.1, U4.5 (XTAL1/CLKIN), Y2.1
PHY_XTAL2: C23.1, U4.4 (XTAL2), Y2.2
RBIAS: R10.1, U4.24 (RBIAS)
RMII_CRS_DV: U4.11 (CRS_DV/MODE2); also elsewhere on the board
RMII_MDC: U4.13 (MDC); also elsewhere on the board
RMII_MDIO: R11.2, U4.12 (MDIO); also elsewhere on the board
RMII_REF_CLK: U4.14 (~INT/REFCLKO); also elsewhere on the board
RMII_RXD0: U4.8 (RXD0/MODE0); also elsewhere on the board
RMII_RXD1: U4.7 (RXD1/MODE1); also elsewhere on the board
RMII_TXD0: U4.17 (TXD0); also elsewhere on the board
RMII_TXD1: U4.18 (TXD1); also elsewhere on the board
RMII_TX_EN: U4.16 (TXEN); also elsewhere on the board
VDDCR: C24.1, U4.6 (VDDCR)

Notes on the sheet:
LAN8742A strap: nINTSEL(LED2) pulled low = REF_CLK Out mode - PHY sources the 50MHz RMII clock to PA1.
J4 has integrated magnetics; connects to the Starlink router / aircraft IP LAN.

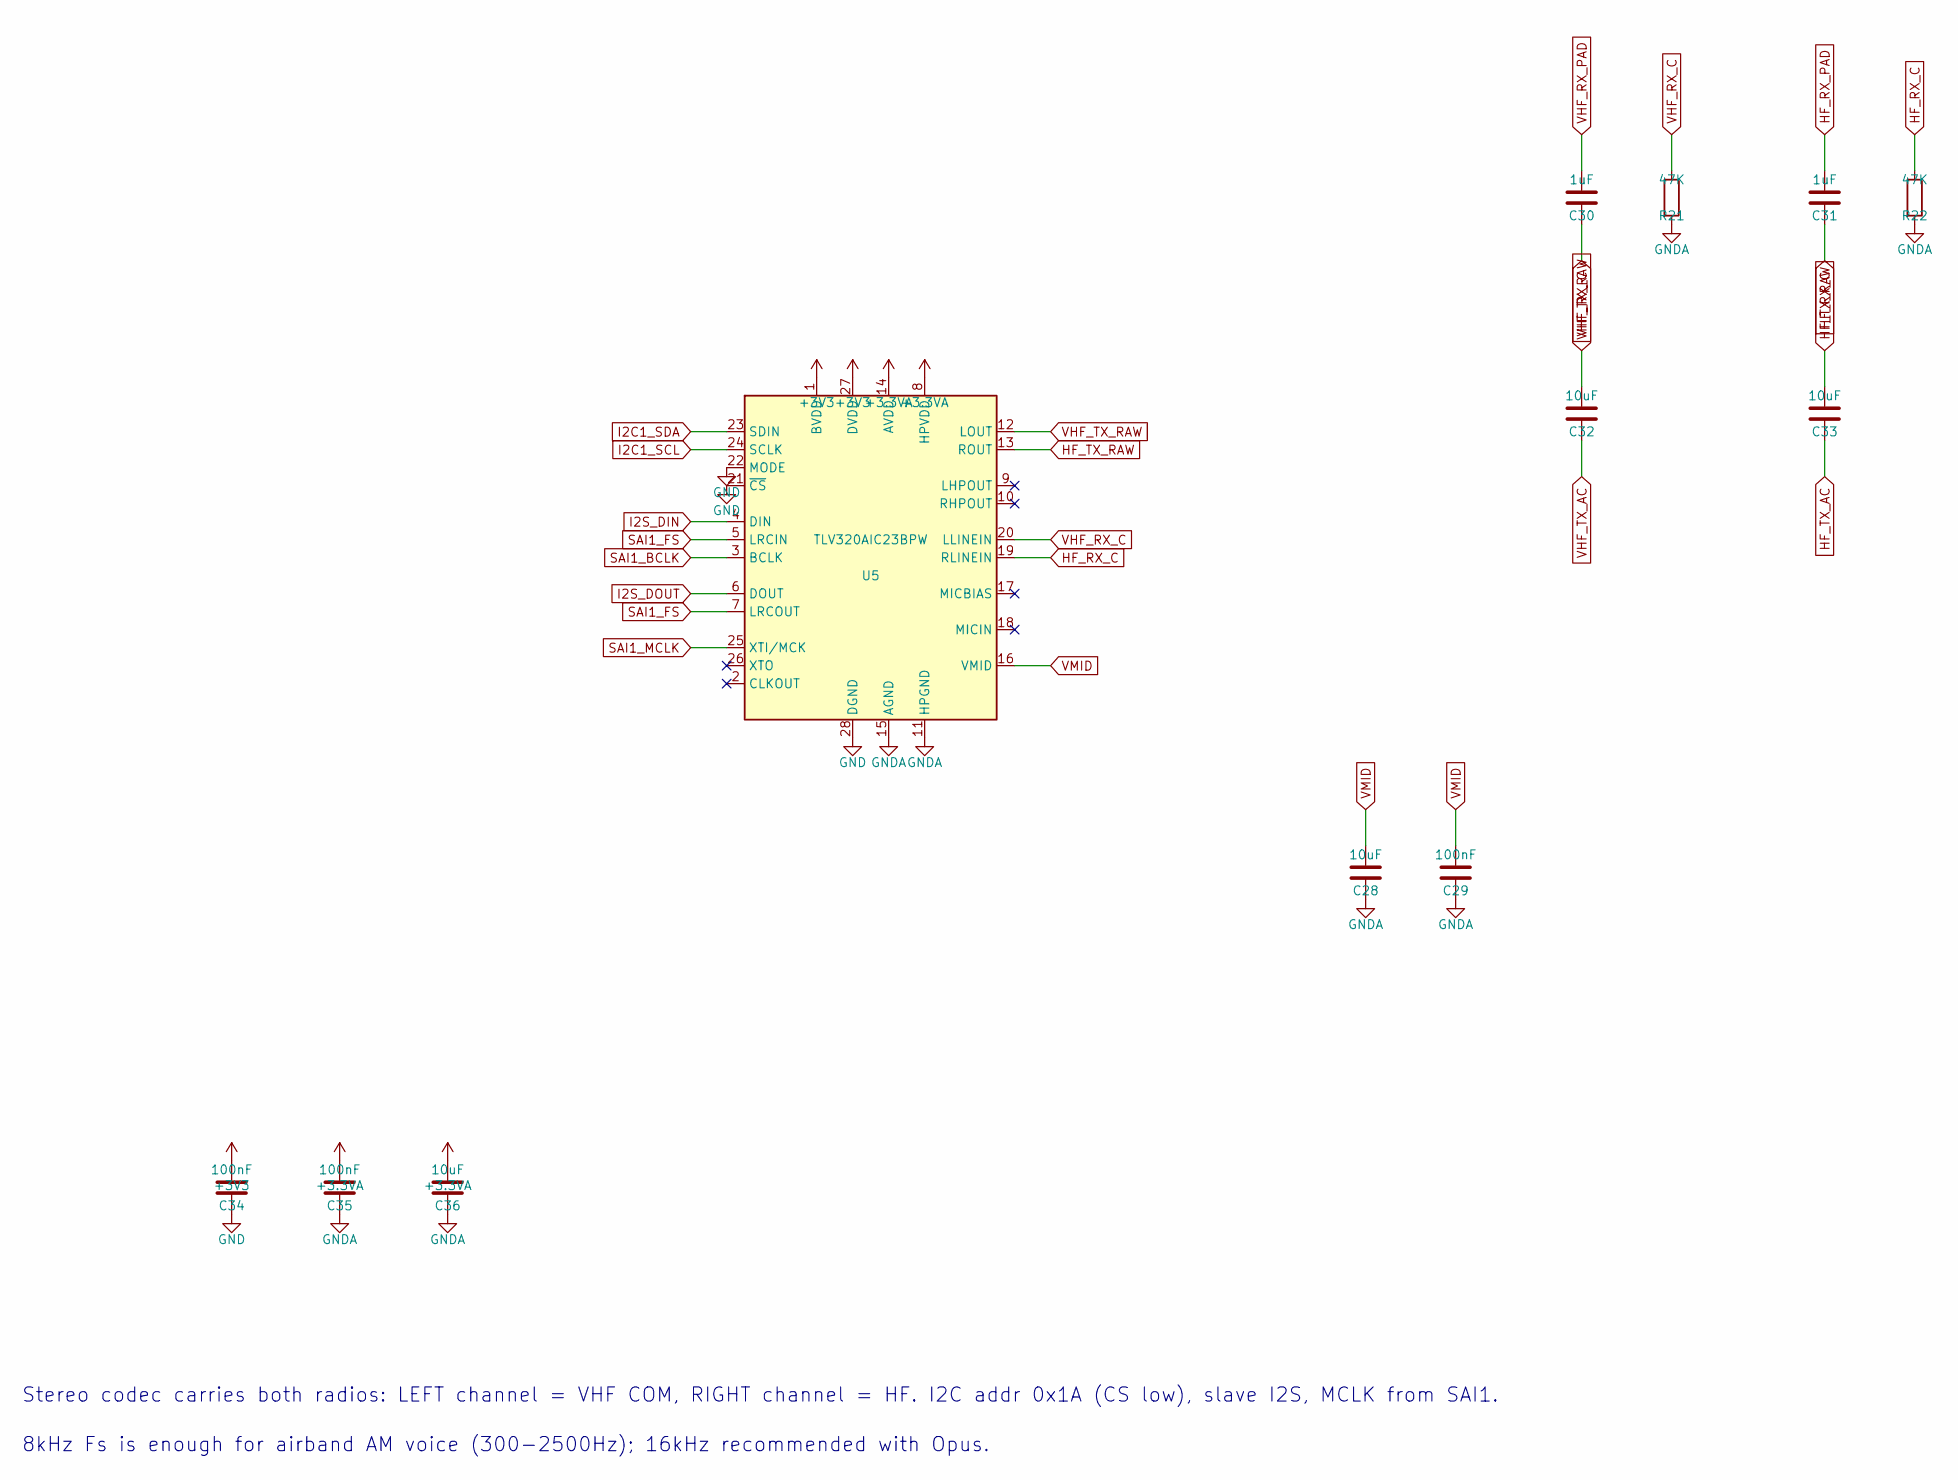
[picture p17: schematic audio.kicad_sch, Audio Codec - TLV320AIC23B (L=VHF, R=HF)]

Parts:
C28, C32, C33, C36: 10uF; C_0805_2012Metric
C29, C34, C35: 100nF; C_0603_1608Metric
C30, C31: 1uF; C_0603_1608Metric
R21, R22: 47K; R_0603_1608Metric
U5: TLV320AIC23BPW; TSSOP-28_4.4x9.7mm_P0.65mm

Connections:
+3V3: C34.1, U5.1 (BVDD), U5.27 (DVDD); also elsewhere on the board
HF_RX_C: C31.2, R22.1, U5.19 (RLINEIN)
HF_RX_PAD: C31.1; also elsewhere on the board
HF_TX_AC: C33.2; also elsewhere on the board
HF_TX_RAW: C33.1, U5.13 (ROUT)
I2C1_SCL: U5.24 (SCLK); also elsewhere on the board
I2C1_SDA: U5.23 (SDIN); also elsewhere on the board
I2S_DIN: U5.4 (DIN); also elsewhere on the board
I2S_DOUT: U5.6 (DOUT); also elsewhere on the board
SAI1_BCLK: U5.3 (BCLK); also elsewhere on the board
SAI1_FS: U5.5 (LRCIN), U5.7 (LRCOUT); also elsewhere on the board
SAI1_MCLK: U5.25 (XTI/MCK); also elsewhere on the board
VHF_RX_C: C30.2, R21.1, U5.20 (LLINEIN)
VHF_RX_PAD: C30.1; also elsewhere on the board
VHF_TX_AC: C32.2; also elsewhere on the board
VHF_TX_RAW: C32.1, U5.12 (LOUT)
VMID: C28.1, C29.1, U5.16 (VMID)

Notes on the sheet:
Stereo codec carries both radios: LEFT channel = VHF COM, RIGHT channel = HF. I2C addr 0x1A (CS low), slave I2S, MCLK from SAI1.
8kHz Fs is enough for airband AM voice (300-2500Hz); 16kHz recommended with Opus.

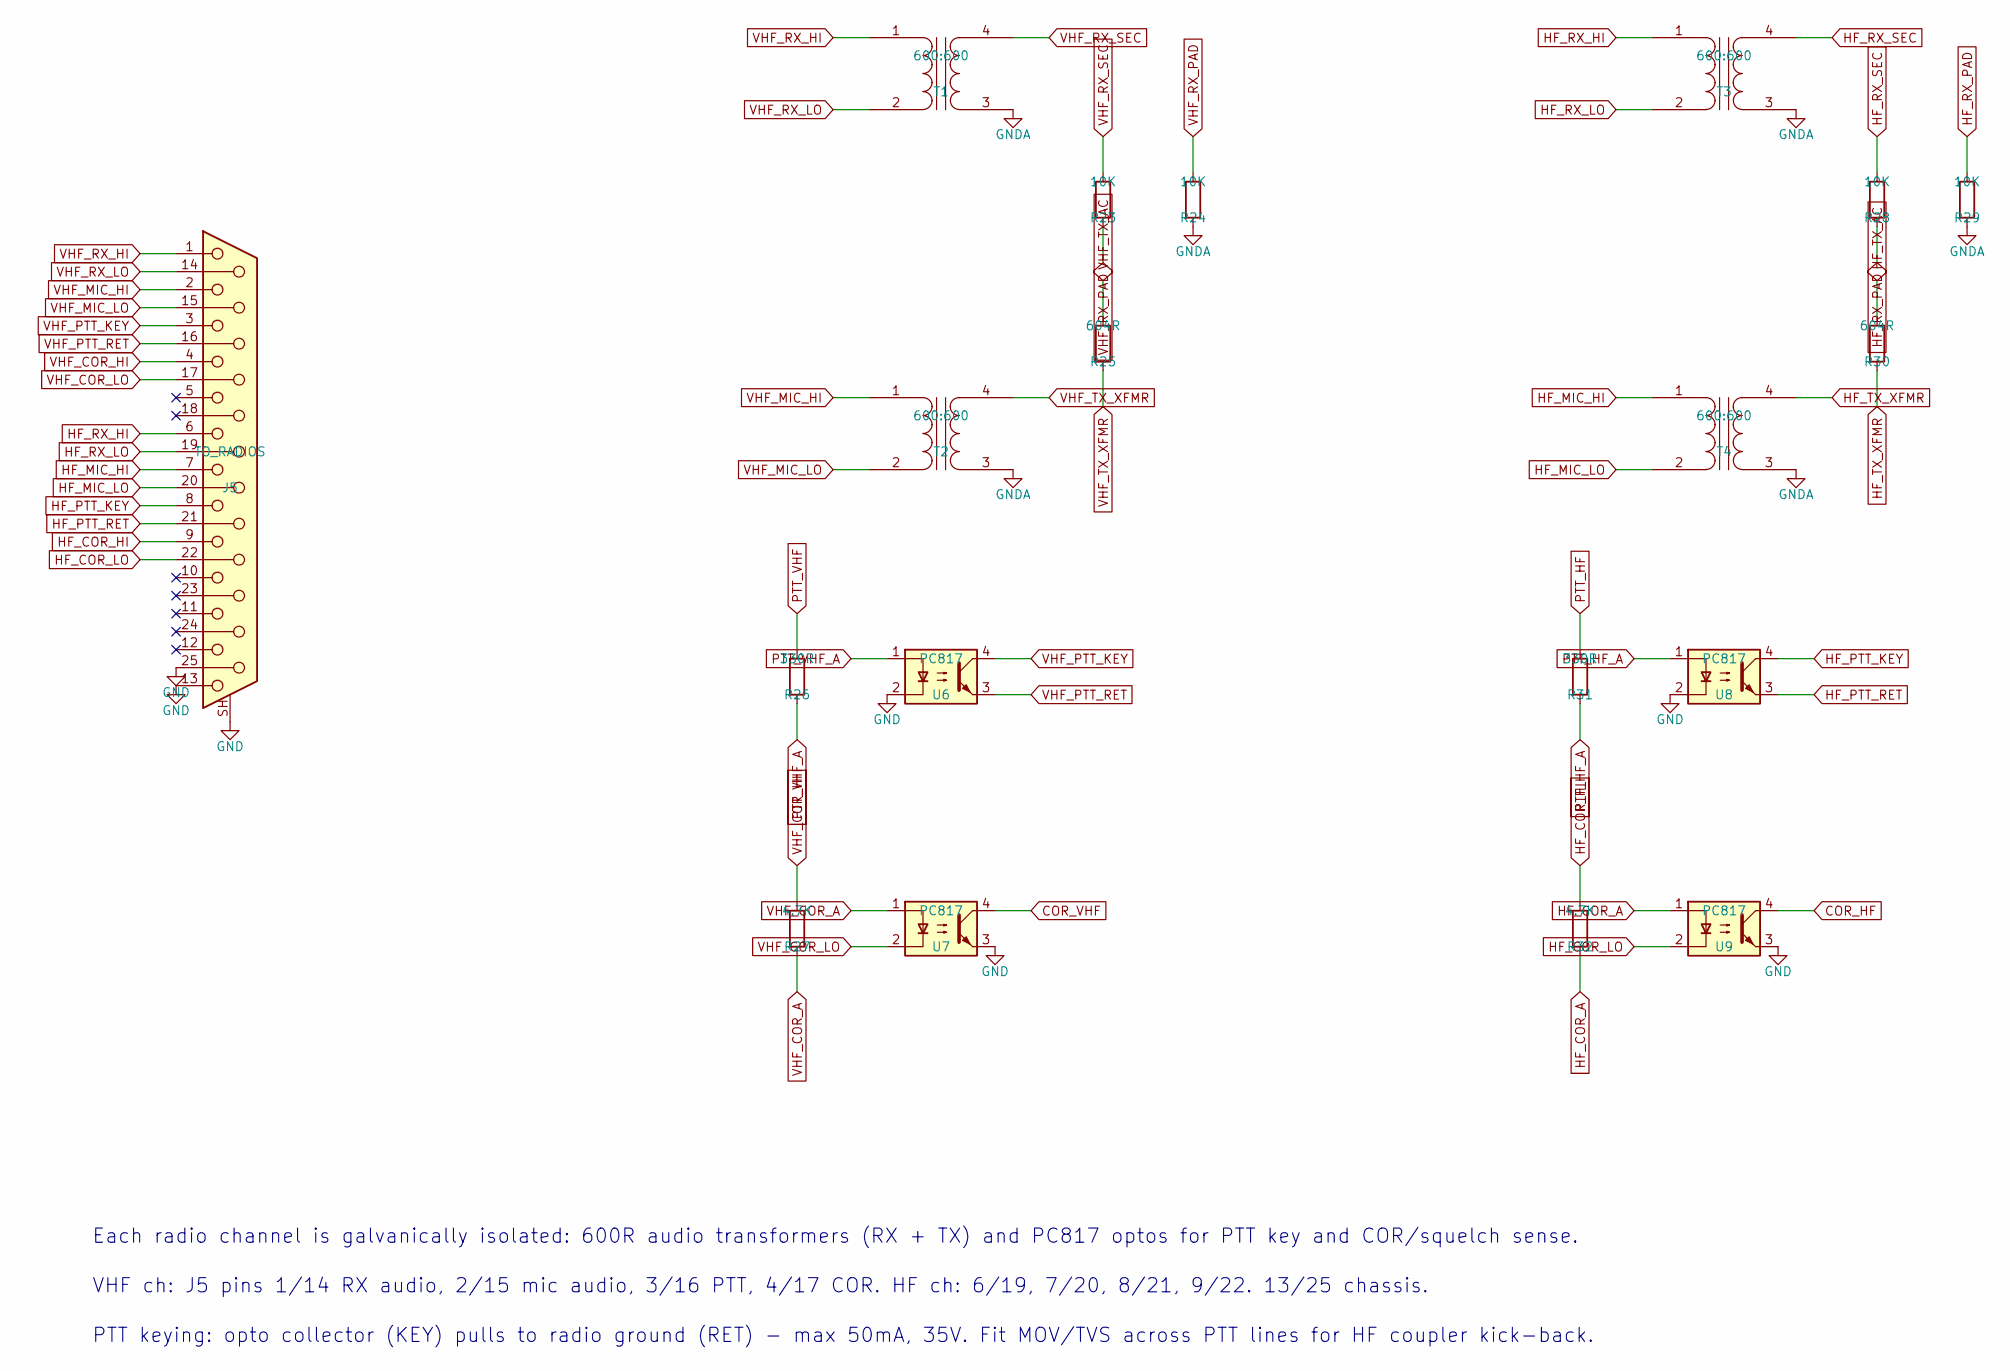
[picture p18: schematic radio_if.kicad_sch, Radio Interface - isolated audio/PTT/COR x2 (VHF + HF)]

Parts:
J5: TO_RADIOS; DSUB-25_Pins_Horizontal_P2.77x2.84mm_EdgePinOffset7.70mm_Ho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
R23, R24, R28, R29: 10K; R_0603_1608Metric
R25, R30: 604R; R_0603_1608Metric
R26, R31: 330R; R_0603_1608Metric
R27, R32: 4.7K; R_0603_1608Metric
T1, T2, T3, T4: 600:600; DIP-4_W10.16mm
U6, U7, U8, U9: PC817; DIP-4_W7.62mm

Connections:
COR_HF: U9.4; also elsewhere on the board
COR_VHF: U7.4; also elsewhere on the board
HF_COR_A: R32.2, U9.1
HF_COR_HI: J5.9, R32.1
HF_COR_LO: J5.22, U9.2
HF_MIC_HI: J5.7, T4.1 (AA)
HF_MIC_LO: J5.20, T4.2 (AB)
HF_PTT_KEY: J5.8, U8.4
HF_PTT_RET: J5.21, U8.3
HF_RX_HI: J5.6, T3.1 (AA)
HF_RX_LO: J5.19, T3.2 (AB)
HF_RX_PAD: R28.2, R29.1; also elsewhere on the board
HF_RX_SEC: R28.1, T3.4 (SB)
HF_TX_AC: R30.1; also elsewhere on the board
HF_TX_XFMR: R30.2, T4.4 (SB)
PTT_HF: R31.1; also elsewhere on the board
PTT_HF_A: R31.2, U8.1
PTT_VHF: R26.1; also elsewhere on the board
PTT_VHF_A: R26.2, U6.1
VHF_COR_A: R27.2, U7.1
VHF_COR_HI: J5.4, R27.1
VHF_COR_LO: J5.17, U7.2
VHF_MIC_HI: J5.2, T2.1 (AA)
VHF_MIC_LO: J5.15, T2.2 (AB)
VHF_PTT_KEY: J5.3, U6.4
VHF_PTT_RET: J5.16, U6.3
VHF_RX_HI: J5.1, T1.1 (AA)
VHF_RX_LO: J5.14, T1.2 (AB)
VHF_RX_PAD: R23.2, R24.1; also elsewhere on the board
VHF_RX_SEC: R23.1, T1.4 (SB)
VHF_TX_AC: R25.1; also elsewhere on the board
VHF_TX_XFMR: R25.2, T2.4 (SB)

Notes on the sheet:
Each radio channel is galvanically isolated: 600R audio transformers (RX + TX) and PC817 optos for PTT key and COR/squelch sense.
VHF ch: J5 pins 1/14 RX audio, 2/15 mic audio, 3/16 PTT, 4/17 COR. HF ch: 6/19, 7/20, 8/21, 9/22. 13/25 chassis.
PTT keying: opto collector (KEY) pulls to radio ground (RET) - max 50mA, 35V. Fit MOV/TVS across PTT lines for HF coupler kick-back.

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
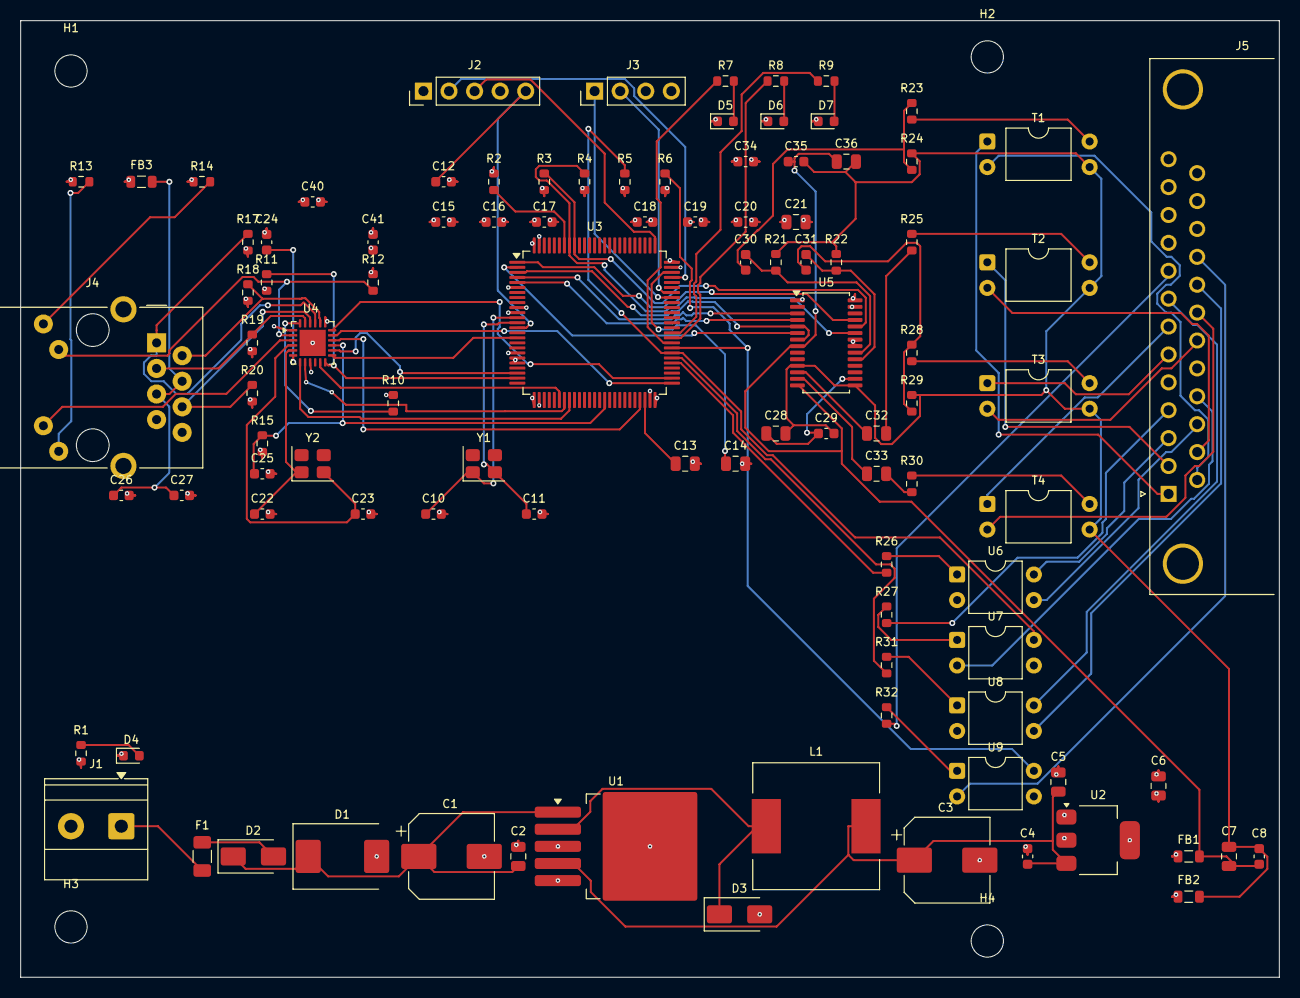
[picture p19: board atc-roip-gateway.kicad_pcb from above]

Board: 4 copper layers, 125.0 x 95.0 mm, 104 parts (0 on the bottom side), 93 nets.

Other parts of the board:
H1, H2, H3, H4: M3; MountingHole_3.2mm_M3

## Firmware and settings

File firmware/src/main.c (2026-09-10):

/* ATC RoIP Gateway - main entry.
 *
 * Superloop architecture: interrupts move audio (SAI DMA) and packets
 * (Ethernet DMA -> lwIP); the loop runs housekeeping.
 */
#include "stm32h7xx_hal.h"
#include "lwip/init.h"
#include "lwip/netif.h"
#include "lwip/timeouts.h"
#include "lwip/dhcp.h"
#include "netif/ethernet.h"

#include "board.h"
#include "app_config.h"
#include "audio/aic23.h"
#include "audio/sai_stream.h"
#include "net/roip_chan.h"
#include "ed137/sip_mini.h"

/* ethernetif_init comes from the STM32CubeH7 lwIP glue (third_party) */
extern err_t ethernetif_init(struct netif *netif);
extern void ethernetif_input(struct netif *netif);

static struct netif gnetif;
static I2C_HandleTypeDef hi2c1;
static UART_HandleTypeDef huart1;
static roip_chan_t chans[CH_COUNT];

/* ------------------------------------------------------------- clocks */
static void SystemClock_Config(void)
{
    /* HSE 25 MHz -> PLL1 -> 480 MHz core; PLL3 -> SAI kernel clock
     * producing 2.048 MHz MCLK for the codec (256 * 8 kHz).
     * Full HAL RCC init generated per STM32CubeMX for STM32H743VIT6;
     * see docs/02-design-spec.md for the clock tree. */
    RCC_OscInitTypeDef osc = {0};
    RCC_ClkInitTypeDef clk = {0};

    HAL_PWREx_ConfigSupply(PWR_LDO_SUPPLY);
    __HAL_PWR_VOLTAGESCALING_CONFIG(PWR_REGULATOR_VOLTAGE_SCALE0);
    while (!__HAL_PWR_GET_FLAG(PWR_FLAG_VOSRDY)) {}

    osc.OscillatorType = RCC_OSCILLATORTYPE_HSE;
    osc.HSEState = RCC_HSE_ON;
    osc.PLL.PLLState = RCC_PLL_ON;
    osc.PLL.PLLSource = RCC_PLLSOURCE_HSE;
    osc.PLL.PLLM = 5;      /* 25/5 = 5 MHz    */
    osc.PLL.PLLN = 192;    /* 5*192 = 960 MHz */
    osc.PLL.PLLP = 2;      /* 480 MHz sysclk  */
    osc.PLL.PLLQ = 4;
    osc.PLL.PLLR = 2;
    osc.PLL.PLLRGE = RCC_PLL1VCIRANGE_2;
    osc.PLL.PLLVCOSEL = RCC_PLL1VCOWIDE;
    HAL_RCC_OscConfig(&osc);

    clk.ClockType = RCC_CLOCKTYPE_SYSCLK | RCC_CLOCKTYPE_HCLK |
                    RCC_CLOCKTYPE_D1PCLK1 | RCC_CLOCKTYPE_PCLK1 |
                    RCC_CLOCKTYPE_PCLK2 | RCC_CLOCKTYPE_D3PCLK1;
    clk.SYSCLKSource = RCC_SYSCLKSOURCE_PLLCLK;
    clk.SYSCLKDivider = RCC_SYSCLK_DIV1;
    clk.AHBCLKDivider = RCC_HCLK_DIV2;
    clk.APB1CLKDivider = RCC_APB1_DIV2;
    clk.APB2CLKDivider = RCC_APB2_DIV2;
    clk.APB3CLKDivider = RCC_APB3_DIV2;
    clk.APB4CLKDivider = RCC_APB4_DIV2;
    HAL_RCC_ClockConfig(&clk, FLASH_LATENCY_4);
}

/* ------------------------------------------------------------- gpio */
static void gpio_init(void)
{
    GPIO_InitTypeDef g = {0};
    __HAL_RCC_GPIOD_CLK_ENABLE();
    __HAL_RCC_GPIOE_CLK_ENABLE();

    g.Pin = PTT_VHF_PIN | PTT_HF_PIN | LED1_PIN | LED2_PIN | LED3_PIN;
    g.Mode = GPIO_MODE_OUTPUT_PP;
    g.Pull = GPIO_NOPULL;
    HAL_GPIO_Init(GPIOD, &g);
    HAL_GPIO_WritePin(GPIOD, PTT_VHF_PIN | PTT_HF_PIN, GPIO_PIN_RESET);

    g.Pin = COR_VHF_PIN | COR_HF_PIN;
    g.Mode = GPIO_MODE_INPUT;
    g.Pull = GPIO_PULLUP;
    HAL_GPIO_Init(GPIOD, &g);

    g.Pin = ETH_NRST_PIN;
    g.Mode = GPIO_MODE_OUTPUT_PP;
    HAL_GPIO_Init(ETH_NRST_PORT, &g);
    HAL_GPIO_WritePin(ETH_NRST_PORT, ETH_NRST_PIN, GPIO_PIN_SET);
}

static void i2c_init(void)
{
    __HAL_RCC_GPIOB_CLK_ENABLE();
    __HAL_RCC_I2C1_CLK_ENABLE();
    GPIO_InitTypeDef g = {0};
    g.Pin = GPIO_PIN_6 | GPIO_PIN_7;
    g.Mode = GPIO_MODE_AF_OD;
    g.Pull = GPIO_NOPULL;      /* external 4.7k pull-ups R3/R4 */
    g.Speed = GPIO_SPEED_FREQ_LOW;
    g.Alternate = GPIO_AF4_I2C1;
    HAL_GPIO_Init(GPIOB, &g);
    hi2c1.Instance = I2C1;
    hi2c1.Init.Timing = 0x10C0ECFF;    /* ~100 kHz from 100 MHz kernel */
    hi2c1.Init.AddressingMode = I2C_ADDRESSINGMODE_7BIT;
    HAL_I2C_Init(&hi2c1);
}

static void uart_init(void)
{
    __HAL_RCC_GPIOA_CLK_ENABLE();
    __HAL_RCC_USART1_CLK_ENABLE();
    GPIO_InitTypeDef g = {0};
    g.Pin = GPIO_PIN_9 | GPIO_PIN_10;
    g.Mode = GPIO_MODE_AF_PP;
    g.Alternate = GPIO_AF7_USART1;
    g.Speed = GPIO_SPEED_FREQ_LOW;
    HAL_GPIO_Init(GPIOA, &g);
    huart1.Instance = USART1;
    huart1.Init.BaudRate = 115200;
    huart1.Init.WordLength = UART_WORDLENGTH_8B;
    huart1.Init.StopBits = UART_STOPBITS_1;
    huart1.Init.Parity = UART_PARITY_NONE;
    huart1.Init.Mode = UART_MODE_TX_RX;
    HAL_UART_Init(&huart1);
}

/* ------------------------------------------------- audio frame callback */
static void audio_frame(const int16_t *rx, int16_t *tx)
{
    /* de-interleave: L = VHF, R = HF */
    static int16_t cap[CH_COUNT][CFG_FRAME_SAMPLES];
    static int16_t play[CH_COUNT][CFG_FRAME_SAMPLES];
    for (int i = 0; i < CFG_FRAME_SAMPLES; i++) {
        cap[CH_VHF][i] = rx[2 * i];
        cap[CH_HF][i] = rx[2 * i + 1];
    }
    uint32_t now = HAL_GetTick();
    for (int c = 0; c < CH_COUNT; c++)
        roip_chan_audio_frame(&chans[c], cap[c], play[c], now);
    for (int i = 0; i < CFG_FRAME_SAMPLES; i++) {
        tx[2 * i] = play[CH_VHF][i];
        tx[2 * i + 1] = play[CH_HF][i];
    }
    HAL_GPIO_WritePin(LED2_PORT, LED2_PIN,
                      chans[CH_VHF].cor_active || chans[CH_VHF].ptt_keyed
                      ? GPIO_PIN_SET : GPIO_PIN_RESET);
    HAL_GPIO_WritePin(LED3_PORT, LED3_PIN,
                      chans[CH_HF].cor_active || chans[CH_HF].ptt_keyed
                      ? GPIO_PIN_SET : GPIO_PIN_RESET);
}

/* ------------------------------------------------- SIP session callback */
static void on_session(roip_channel_id_t id, bool up,
                       const ip_addr_t *peer, uint16_t rtp_port)
{
    if (up)
        roip_chan_set_peer(&chans[id], peer, rtp_port);
    roip_chan_session(&chans[id], up);
    HAL_GPIO_WritePin(LED1_PORT, LED1_PIN,
                      (chans[CH_VHF].session_up || chans[CH_HF].session_up)
                      ? GPIO_PIN_SET : GPIO_PIN_RESET);
}

int main(void)
{
    HAL_Init();
    SystemClock_Config();
    SCB_EnableICache();
    SCB_EnableDCache();
    gpio_init();
    i2c_init();
    uart_init();

    /* PHY hardware reset pulse */
    HAL_GPIO_WritePin(ETH_NRST_PORT, ETH_NRST_PIN, GPIO_PIN_RESET);
    HAL_Delay(10);
    HAL_GPIO_WritePin(ETH_NRST_PORT, ETH_NRST_PIN, GPIO_PIN_SET);
    HAL_Delay(50);

    /* network */
    lwip_init();
    ip4_addr_t ip, mask, gw;
    ip4_addr_set_zero(&ip);
    ip4_addr_set_zero(&mask);
    ip4_addr_set_zero(&gw);
#if !CFG_USE_DHCP
    ip4addr_aton(CFG_STATIC_IP, &ip);
    ip4addr_aton(CFG_STATIC_MASK, &mask);
    ip4addr_aton(CFG_STATIC_GW, &gw);
#endif
    netif_add(&gnetif, &ip, &mask, &gw, NULL, ethernetif_init,
              ethernet_input);
    netif_set_default(&gnetif);
    netif_set_up(&gnetif);
#if CFG_USE_DHCP
    dhcp_start(&gnetif);
#endif

    /* audio */
    aic23_init(&hi2c1);
    sai_stream_init(audio_frame);
    sai_stream_start();

    /* RoIP channels */
    roip_chan_init(&chans[CH_VHF], CH_VHF, CFG_RTP_PORT_VHF);
    roip_chan_init(&chans[CH_HF], CH_HF, CFG_RTP_PORT_HF);
#if CFG_SIP_ENABLE
    sip_init(on_session);
#else
    ip_addr_t peer;
    ipaddr_aton(CFG_STATIC_PEER_IP, &peer);
    roip_chan_set_peer(&chans[CH_VHF], &peer, CFG_STATIC_PEER_PORT_VHF);
    roip_chan_set_peer(&chans[CH_HF], &peer, CFG_STATIC_PEER_PORT_HF);
    roip_chan_session(&chans[CH_VHF], true);
    roip_chan_session(&chans[CH_HF], true);
#endif

    uint32_t last_poll = 0;
    for (;;) {
        ethernetif_input(&gnetif);
        sys_check_timeouts();
        uint32_t now = HAL_GetTick();
        if (now != last_poll) {
            last_poll = now;
            roip_chan_poll(&chans[CH_VHF], now);
            roip_chan_poll(&chans[CH_HF], now);
#if CFG_SIP_ENABLE
            sip_poll(now);
#endif
        }
    }
}

void SysTick_Handler(void)
{
    HAL_IncTick();
}

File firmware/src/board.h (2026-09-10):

/* ATC RoIP Gateway - board pin map (schematic rev A)
 *
 * MCU: STM32H743VIT6 (LQFP-100), HSE 25 MHz crystal.
 */
#ifndef BOARD_H
#define BOARD_H

#include "stm32h7xx_hal.h"

/* ---- RMII to LAN8742A --------------------------------------------------- */
#define ETH_REF_CLK_PIN    GPIO_PIN_1   /* PA1  */
#define ETH_MDIO_PIN       GPIO_PIN_2   /* PA2  */
#define ETH_MDC_PIN        GPIO_PIN_1   /* PC1  */
#define ETH_CRS_DV_PIN     GPIO_PIN_7   /* PA7  */
#define ETH_RXD0_PIN       GPIO_PIN_4   /* PC4  */
#define ETH_RXD1_PIN       GPIO_PIN_5   /* PC5  */
#define ETH_TX_EN_PIN      GPIO_PIN_11  /* PB11 */
#define ETH_TXD0_PIN       GPIO_PIN_12  /* PB12 */
#define ETH_TXD1_PIN       GPIO_PIN_13  /* PB13 */
#define ETH_NRST_PORT      GPIOE        /* PHY hardware reset */
#define ETH_NRST_PIN       GPIO_PIN_10  /* PE10 */
#define ETH_PHY_ADDR       0            /* RXER/PHYAD0 floating -> 0 */

/* ---- SAI1 to TLV320AIC23B ----------------------------------------------- */
#define SAI_MCLK_PIN       GPIO_PIN_2   /* PE2  SAI1_MCLK_A */
#define SAI_BCLK_PIN       GPIO_PIN_5   /* PE5  SAI1_SCK_A  */
#define SAI_FS_PIN         GPIO_PIN_4   /* PE4  SAI1_FS_A   */
#define SAI_SD_OUT_PIN     GPIO_PIN_6   /* PE6  SAI1_SD_A -> codec DIN  */
#define SAI_SD_IN_PIN      GPIO_PIN_3   /* PE3  SAI1_SD_B <- codec DOUT */

/* ---- Codec control ------------------------------------------------------ */
#define CODEC_I2C          I2C1         /* PB6 SCL / PB7 SDA */
#define CODEC_I2C_ADDR     (0x1A << 1)  /* CS pin low        */

/* ---- Radio discrete I/O (through PC817 optos) --------------------------- */
#define PTT_VHF_PORT       GPIOD
#define PTT_VHF_PIN        GPIO_PIN_8   /* PD8, high = key VHF PTT  */
#define PTT_HF_PORT        GPIOD
#define PTT_HF_PIN         GPIO_PIN_9   /* PD9, high = key HF PTT   */
#define COR_VHF_PORT       GPIOD
#define COR_VHF_PIN        GPIO_PIN_10  /* PD10, low = VHF squelch open */
#define COR_HF_PORT        GPIOD
#define COR_HF_PIN         GPIO_PIN_11  /* PD11, low = HF squelch open  */

/* ---- Status LEDs / console ---------------------------------------------- */
#define LED1_PORT GPIOD
#define LED1_PIN  GPIO_PIN_12           /* link/session */
#define LED2_PORT GPIOD
#define LED2_PIN  GPIO_PIN_13           /* VHF activity */
#define LED3_PORT GPIOD
#define LED3_PIN  GPIO_PIN_14           /* HF activity  */
#define CONSOLE_UART       USART1       /* PA9 TX / PA10 RX, 115200 8N1 */

#endif /* BOARD_H */

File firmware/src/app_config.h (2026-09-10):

/* ATC RoIP Gateway - application configuration (compile-time defaults;
 * most values are also adjustable at runtime over the UART console). */
#ifndef APP_CONFIG_H
#define APP_CONFIG_H

#include <stdint.h>
#include <stdbool.h>

/* ---- Network ------------------------------------------------------------ */
#define CFG_USE_DHCP          1
#define CFG_STATIC_IP         "192.168.1.80"     /* used when DHCP off      */
#define CFG_STATIC_MASK       "255.255.255.0"
#define CFG_STATIC_GW         "192.168.1.1"

/* ---- Session mode -------------------------------------------------------
 * SIP mode: the gateway is an ED-137-style radio endpoint; the ground VCS /
 * remote operator INVITEs each channel URI (vhf@<ip>, hf@<ip>).
 * STATIC mode: no signalling, RTP flows to/from a fixed peer (bring-up). */
#define CFG_SIP_ENABLE        1
#define CFG_SIP_PORT          5060
#define CFG_STATIC_PEER_IP    "192.168.1.10"
#define CFG_RTP_PORT_VHF      5004               /* local RTP ports         */
#define CFG_RTP_PORT_HF       5006
#define CFG_STATIC_PEER_PORT_VHF 5004
#define CFG_STATIC_PEER_PORT_HF  5006

/* ---- Audio / RTP -------------------------------------------------------- */
#define CFG_SAMPLE_RATE       8000               /* ED-137 radio: 8 kHz     */
#define CFG_FRAME_MS          20                 /* RTP packet duration     */
#define CFG_FRAME_SAMPLES     (CFG_SAMPLE_RATE * CFG_FRAME_MS / 1000)
#define CFG_PAYLOAD_TYPE      0                  /* PCMU (G.711 u-law)      */
#define CFG_JITTER_MIN_MS     40
#define CFG_JITTER_MAX_MS     120
#define CFG_R2S_PERIOD_MS     200                /* keepalive when idle     */

/* ---- PTT / COR behaviour ------------------------------------------------ */
#define CFG_PTT_MAX_MS        120000             /* stuck-PTT guard (2 min) */
#define CFG_COR_DEBOUNCE_MS   20
#define CFG_HF_TUNE_DELAY_MS  50    /* PTT->audio delay for HF coupler keying */

/* ---- VOX (used when a radio has no COR line wired) ---------------------- */
#define CFG_VOX_ENABLE_VHF    0
#define CFG_VOX_ENABLE_HF     0
#define CFG_VOX_THRESH_DB     -30
#define CFG_VOX_HANG_MS       350

typedef enum { CH_VHF = 0, CH_HF = 1, CH_COUNT = 2 } roip_channel_id_t;

#endif /* APP_CONFIG_H */

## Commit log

2026-09-10 ATC RoIP Gateway rev A: schematics, routed PCB, BOM, firmware, docs
    Airborne Radio-over-IP gateway bridging VHF COM + HF transceivers to an
    IP network (Starlink) with an ED-137-style RTP/PTT/COR stream.
    - KiCad schematics (6 sheets, ERC clean) and routed 4-layer PCB
    (0 unconnected, 0 electrical DRC), fab outputs included
    - Complete BOM with manufacturer part numbers
    - STM32H743 firmware: minimal SIP, RTP with ED-137 header extension,
    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
    [BOM.csv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]
2026-09-12 Add JLCPCB-format placement list (CPL) and BOM
    tools/make_jlc.py converts the KiCad pick-and-place export and docs/BOM.csv
    into JLCPCB's upload columns (Designator/Mid X/Mid Y/Layer/Rotation and
    Comment/Designator/Footprint/LCSC Part #/Manufacturer/MPN). The LCSC column is
    left blank on purpose so the uploader matches on MPN and each match is
    confirmed by a person. The script cross-checks that every placed part is in
    the BOM and vice versa.
    [atc-roip-gateway-bom-jlcpcb.csv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]
2026-09-13 JLCPCB BOM: descriptive comments, optional LCSC map
    [atc-roip-gateway-bom-jlcpcb.csv]
2026-09-13 JLCPCB BOM: explicit Quantity column
    [atc-roip-gateway-bom-jlcpcb.csv]
